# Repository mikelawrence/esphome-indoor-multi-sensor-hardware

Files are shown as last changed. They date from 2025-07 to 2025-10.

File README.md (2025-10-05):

# ESPHome Indoor Multi-Sensor Hardware

<p align="center">
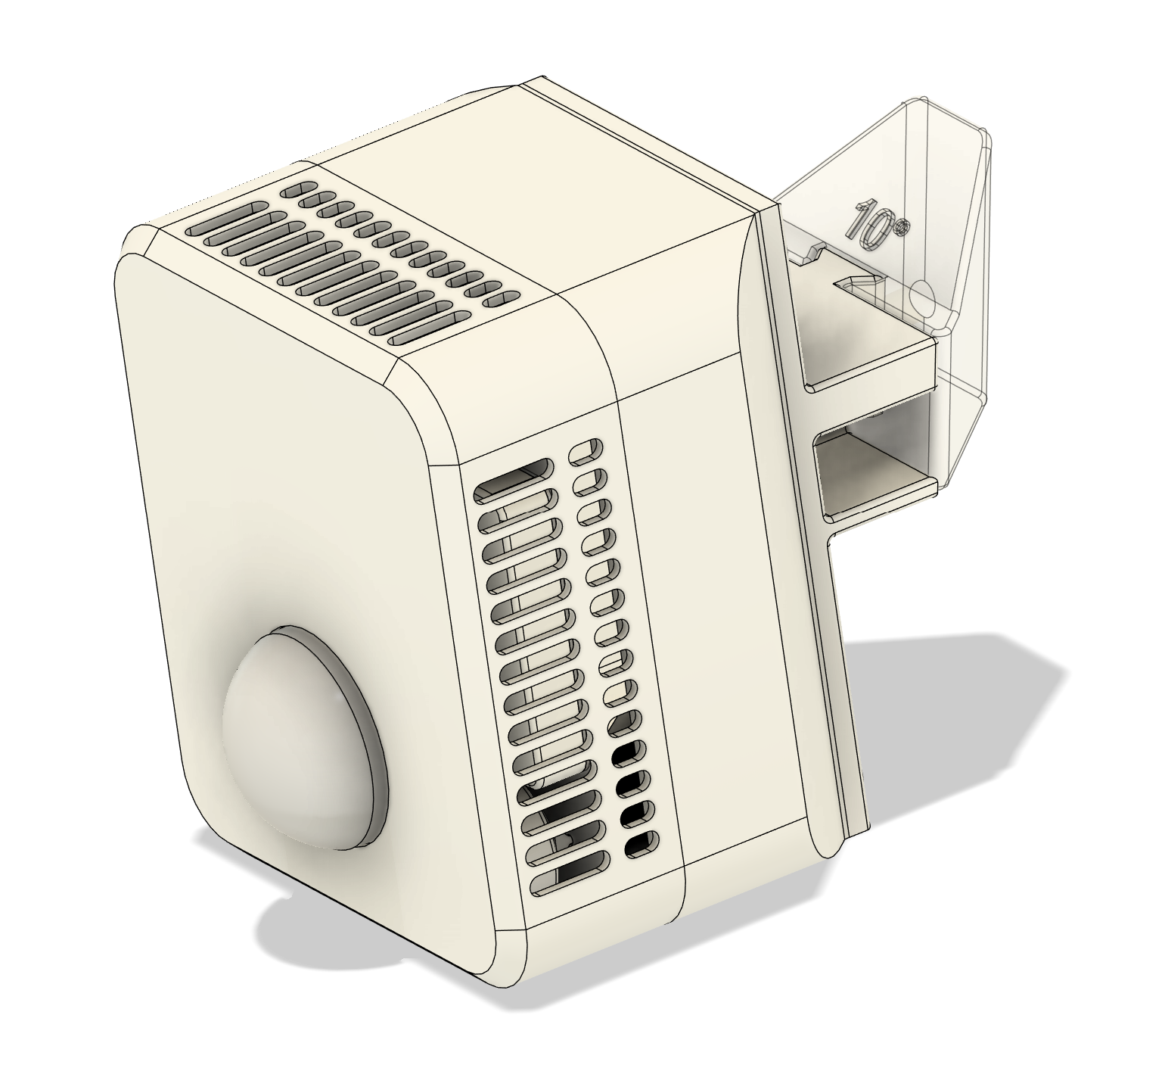
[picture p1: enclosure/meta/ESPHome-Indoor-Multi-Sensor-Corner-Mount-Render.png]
  
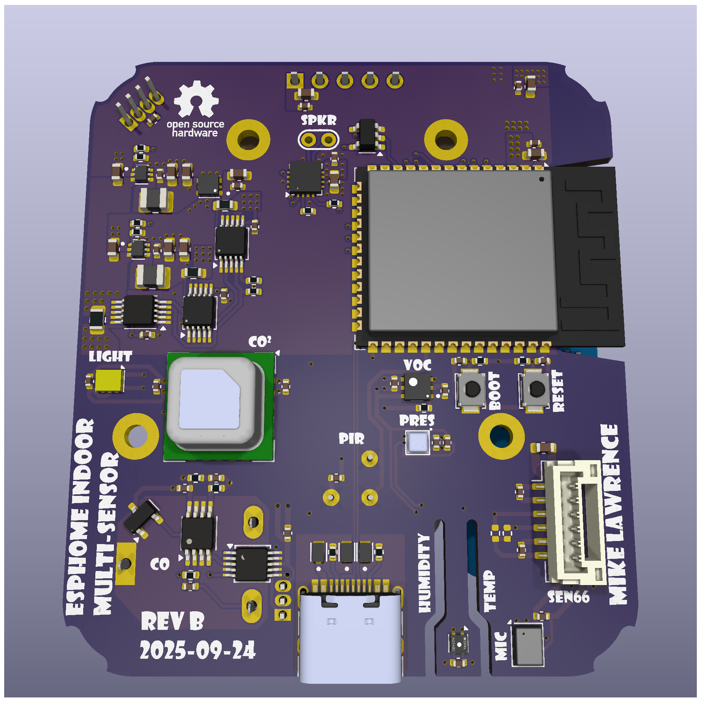
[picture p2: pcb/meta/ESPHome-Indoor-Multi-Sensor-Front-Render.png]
  
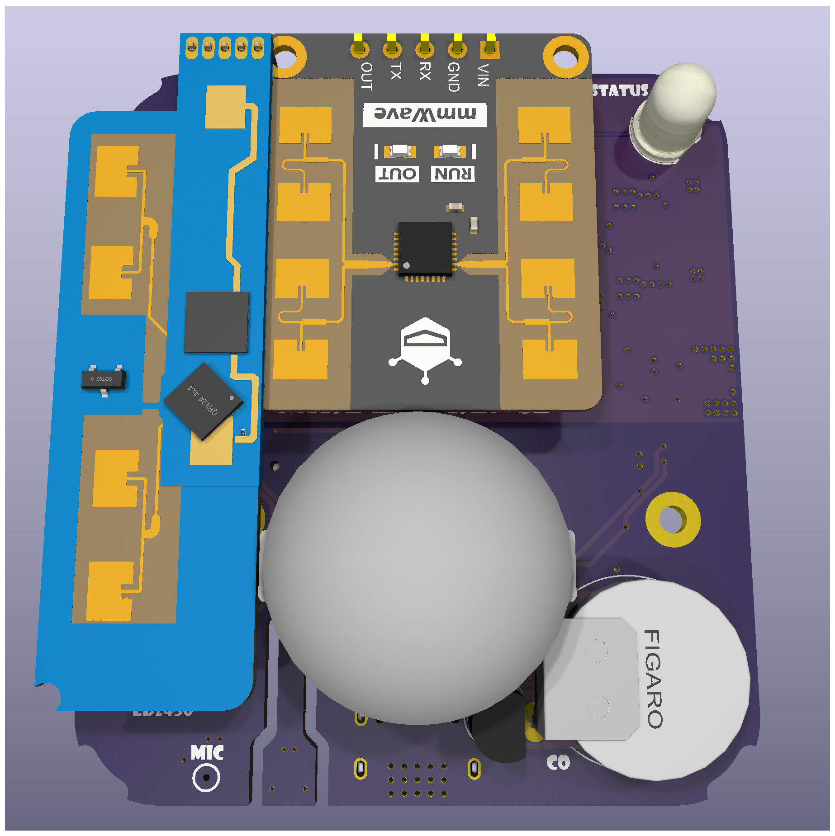
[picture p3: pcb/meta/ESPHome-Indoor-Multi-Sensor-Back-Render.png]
  
</p>

There are a lot of presence sensors using a combination of PIR and High Frequency Radar Human Presence Detectors to get a combination of quick response and low movement detection like when sleeping. Good examples of these types of sensor are the [Everything Presence One](https://shop.everythingsmart.io/products/everything-presence-one-kit) and [Roomsense IQ](https://www.roomsenselabs.com/). The later has a sensor module that you can add to support all sorts readings like Particular Matter (PM) Carbon Monoxide. But since I like to do everything myself. I started thinking about how I would approach this and more specifically what sensors did I want.

I settled on the following characteristics:

* ESP32-S3
* ESPHome software development
* USB-C Power
* Multiple options for Radar presence detection modules
  - Hi-Link LD2410B
  - Hi-Link LD2410S
  - Hi-Link LD2420
  - Hi-Link LD2450
  - DFRobot C4001 (SEN609 and SEN610)
* PIR (Panasonic)
* Sensirion SEN66 All-in-One (Package A)
  - Temperature
  - Humidity
  - Particulate Matter (PM) 
  - CO₂
  - Volatile Organic Compound (VOC)
  - Nitrogen Oxide (NOₓ)
* Or individual Sensors (Package B)
  - Sensirion SHT4X Temperature and Humidity
  - Sensirion SCD4X CO₂
  - Sensirion SGP4X VOC and NOₓ
* Bosch BMP581 Pressure
* Figaro TGS5141 Carbon Monoxide (CO)
* AMS TSL2591 Light
* Microphone for sound levels
* A Speaker for alerts
* INA228 Power and Energy Monitor

## Status
* **Rev -:** Has been fabricated and tested. I had JLCPCB fabricate the boards and I self assembled using a Home-Brew reflow oven by [Whizoo Controleo3](https://whizoo.com/). All circuits have been tested and found to be operational. 
* **Rev A:** There was an issue with signal integrity on the I²C bus when communicating with the SEN66. To fix the problem I added stronger pullups and a new and dedicated I²C bus to the SEN66. Thus Rev A was born. This revision was never fabricated. But all my Rev - boards have been modified to Rev A.
* **Rev B:** Added support for the LD2410S/LD2420 Radars, CO temperature sensor and INA238 power monitors for 3.3V and 3.3VA. Removed Radar power control. Board has been fabricated and testing has begun.

## Design Decisions
### ESP32 and ESPHome
ESPHome is closely aligned with Home Assistant. In fact they are the same company. Home Assistant uses ESPHome for some of their hardware like the [Home Assistant Voice Preview Edition](https://www.home-assistant.io/voice-pe/) or [Bluetooth Proxy](https://esphome.io/components/bluetooth_proxy.html). I chose a newer ESP32-S3 for this design which also has Bluetooth support.

This project uses ESP32-S3-WROOM-2-N32R16V which has an enormous 32MB of flash and 16MB of octal PSRAM. These specs are way out of the normal range for an ESP32, so why? First I wanted to be able to store sounds directly on the unit itself mainly so it can sound out alerts even if Home Assistant is not connected. The PSRAM came along with the big Flash but it also has benefits. Sound pressure analysis likes more PSRAM and so does Bluetooth Proxying.

### Sensors
#### Radar based Human Presence Sensors
Three of the Hi-Link sensors (LS2410B, LD2420 and LD2450) are supported by ESPHome directly but the DFRobot C4001 and LD2410S are not directly supported. This project uses the LD2410 component without change. For the LD2450 I have created a config that allows you to specify an installation angle, handle coordinate transforms and all zone detection. I created (with help from the Internet) a nice Home Assistant Lovelace configuration to visualize the installation angle and zone [here](https://mikelawrence.github.io/esphome-indoor-multi-sensor-config/home-assistant.html) for the LD2450 Radar and the LD2410 Radar's Gate configuration. For the DFRobot C4001 Radar I wrote an ESPHome External Component and created a [Pull Request](https://github.com/esphome/esphome/pull/9810) to add it to ESPHome. However the DFRobot team has since started their own [Pull Request](https://github.com/esphome/esphome/pull/10675). I will add support for their Pull Request when it comes out of draft and works. There is a [Pull Request](https://github.com/esphome/esphome/pull/8486) for the LD2410S. I will add support soon for the LD2410S and LD2420 Radars.

#### Sensor choices
The [SEN66](https://sensirion.com/products/catalog/SEN66) may be an expensive sensor package but it does it all, Temperature, Humidity, PM, CO₂, VOC and NOₓ. A tiny fan is primarily used for measuring PM but it also moves air by the temperature and humidity sensors making them fairly responsive. I call this Package A. If you choose not use the SEN66 you can populate the Package B individual sensors ([SHT4X](https://sensirion.com/media/documents/33FD6951/67EB9032/HT_DS_Datasheet_SHT4x_5.pdf), [SCD4X](https://sensirion.com/media/documents/48C4B7FB/67FE0194/CD_DS_SCD4x_Datasheet_D1.pdf) and [SGP4X](https://sensirion.com/media/documents/A056FE9C/61E970C2/Sensirion_Flyer_Gas_Sensors_Web.pdf)) to get Temperature, Humidity, CO₂, VOC and NOₓ. The only thing missing is PM.

#### Carbon Monoxide
For some reason CO sensors are not as common as CO₂ sensors. Most are expensive and have short life spans. The  Figaro TGS5141 is inexpensive and has a 10-year life span but it isn't a nice all-in-one with I²C interface. You have to add a transimpedance amplifier and then digitize the analog signal. I chose to add an ADS1115 16-bit ADC right next to the transimpedance amplifier instead of running analog signal across the board to the questionable ESP32 built in ADC. The ADS1115 also a has true differential Programmable Gain Amplifier on the input. This reduces the CO sensor circuit complexity. This sensor is not going to be very accurate but detection of CO in even low levels is probably a reason for concern. So even if not a safety sensor it can help.

I verified the CO circuit using CO Bump Gas. It doesn't calibrate, but it will prove that the sensor responds to the presence of CO. I used a small upside down container on my outside bench with the sensor I wanted to test inside. Squirting some bump gas inside with the thin straw showed that 4 out of 5 sensors responded to the gas. The 5'th that didn't respond had a solder bridge between two pins on the transimpedance amplifier. A quick removal of the solder bridge fixed the non-functioning sensor.

Rev B adds a DS18S20 temperature sensor to the design for CO calibration. The intent is to glue it to the CO sensor and use that for temperature calibration instead of using the ambient temp or the SHT4X sensor on the other side of the board.

> [!WARNING]
> This CO sensor is not rated for safety nor is it particularly accurate. Use at your own risk! I still have UL listed (American) CO detectors as my main line of defense.

#### Pressure and Light
The [BMP581](https://www.bosch-sensortec.com/media/boschsensortec/downloads/datasheets/bst-bmp581-ds004.pdf) pressure sensor is primarily used as a barometric pressure sensor but it is sensitive enough for micro-pressure changes like when a door is closed. Pressure can also be used to compensate the CO₂ sensor in either the SEN6X or the SCD4X. Light is another measurement that may or may not be helpful but I included it. Keep in mind that this measurement is inside an enclosure thus has some significant limitations when it comes to accuracy.

#### Speaker and Microphone
The SEN66 takes up a lot of space so a small speaker is necessary. I choose a flat speaker from [Same Sky](https://www.sameskydevices.com/product/audio/speakers/miniature-(10-mm~40-mm)/cms-251437-24sp-x8) and started playing. My first attempts were pretty, flat, meaning these small speakers don't move a lot of air and in free space they have almost no volume. After doing some research it became clear, the speaker needs a enclosure. I was able to come up with a small 3D printed enclosure attached to the PCB itself. Man what a difference. This 2W speaker kicks some serious butt.

I threw in the microphone to measure sound levels. The intent is listen for noise as additional presence detection.

#### Power and Energy Monitor
The [INA228](https://www.ti.com/lit/ds/symlink/ina228.pdf) power and energy monitor can give instantaneous readings of voltage, current and power but it also measures energy over time (WHr).

### USB-C Power
The board does not use USB-C Power Delivery but I am expecting 5V @ 3A which is readily available for most USB-C Power Bricks. The PCB has the appropriate resistors on the CC pins which will request 5V @ 3A from a USB-C Power Brick. The board does not need anywhere close to 3A but peaks near 0.75A are possible so be careful using a USB 2.0 Power Brick with a 0.5A default current. Actual testing shows a 1W average for the Package A version and slightly less than 0.9W average for the Package B option as measured by the INA228. Quick calculations show about 8.1kWh/yr for Package A and 7.3kWh/yr for Package B. In Texas that is less than $1 per year. These number are for Rev -.

## Enclosure
<p align="center">
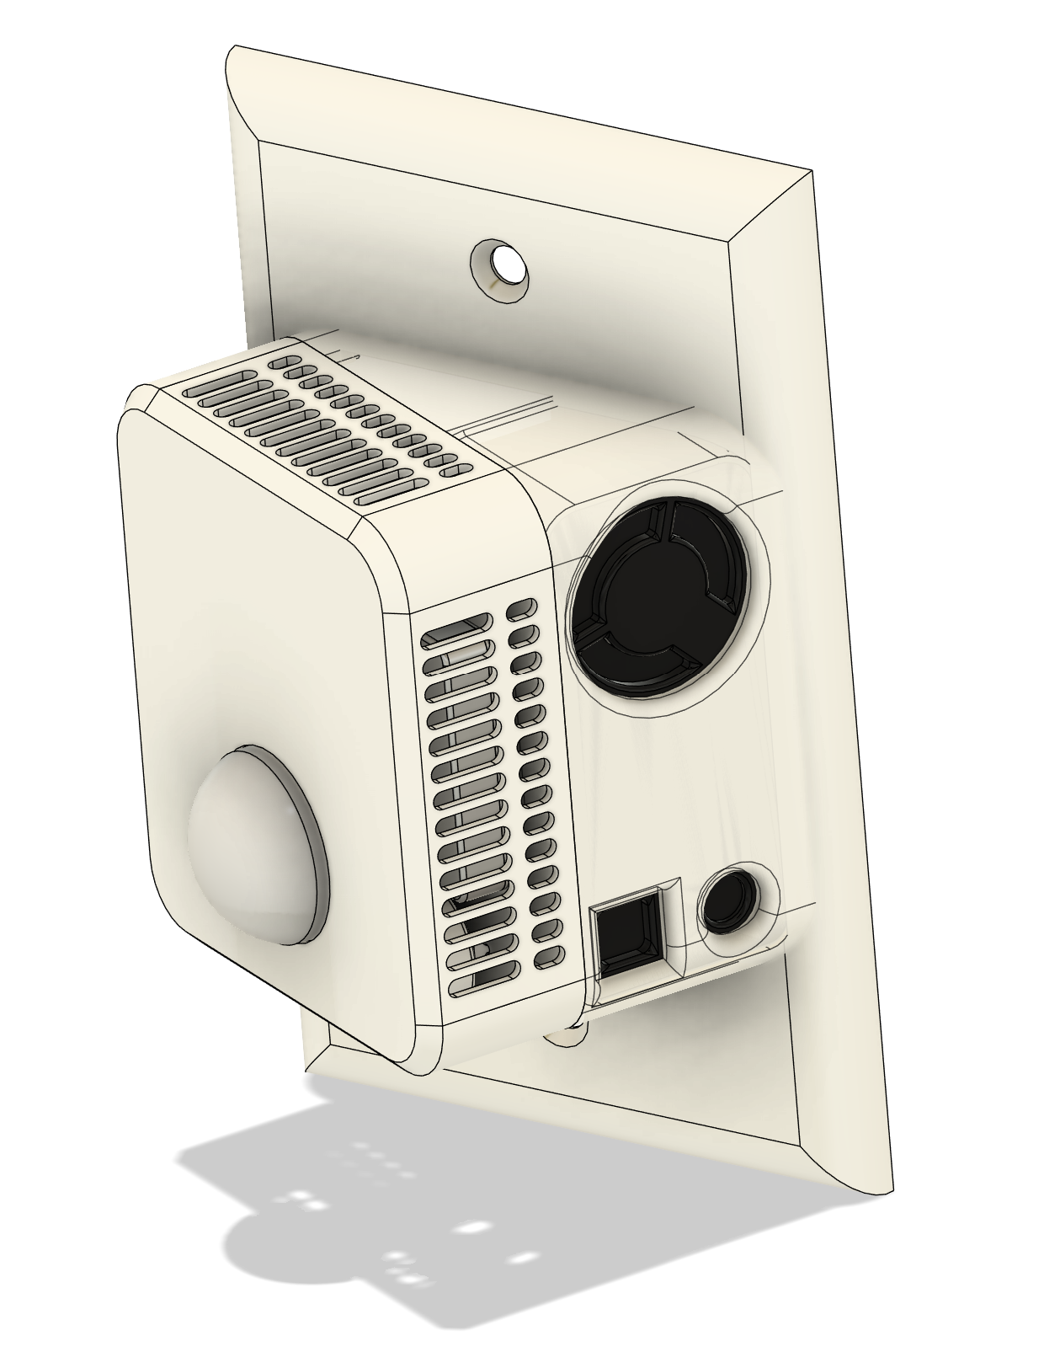
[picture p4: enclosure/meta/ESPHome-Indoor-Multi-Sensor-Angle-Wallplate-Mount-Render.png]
  
</p>

More information is in the enclosure [README](enclosure/README.md) file.

## Configuration
Click [here](https://mikelawrence.github.io/esphome-indoor-multi-sensor-config/) to go to the installation and configuration repository.

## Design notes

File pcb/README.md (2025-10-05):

# ESPHome Indoor Multi-Sensor PCB
<p align="center">
  
  
</p>

The PCB is designed in [KiCad](https://www.kicad.org/). Fabrication and is tuned toward [JCLPCB](https://jlcpcb.com/). I chose not to use JLCPCB for assembly because they had a hard time with some the parts I included in this design. When I had the boards fabricated I also had them panelize two PCBs and produce a stencil for both for the panelized boards.

* **Rev -**: Is currently being fabricated. 

## Schematic
<p align="center">
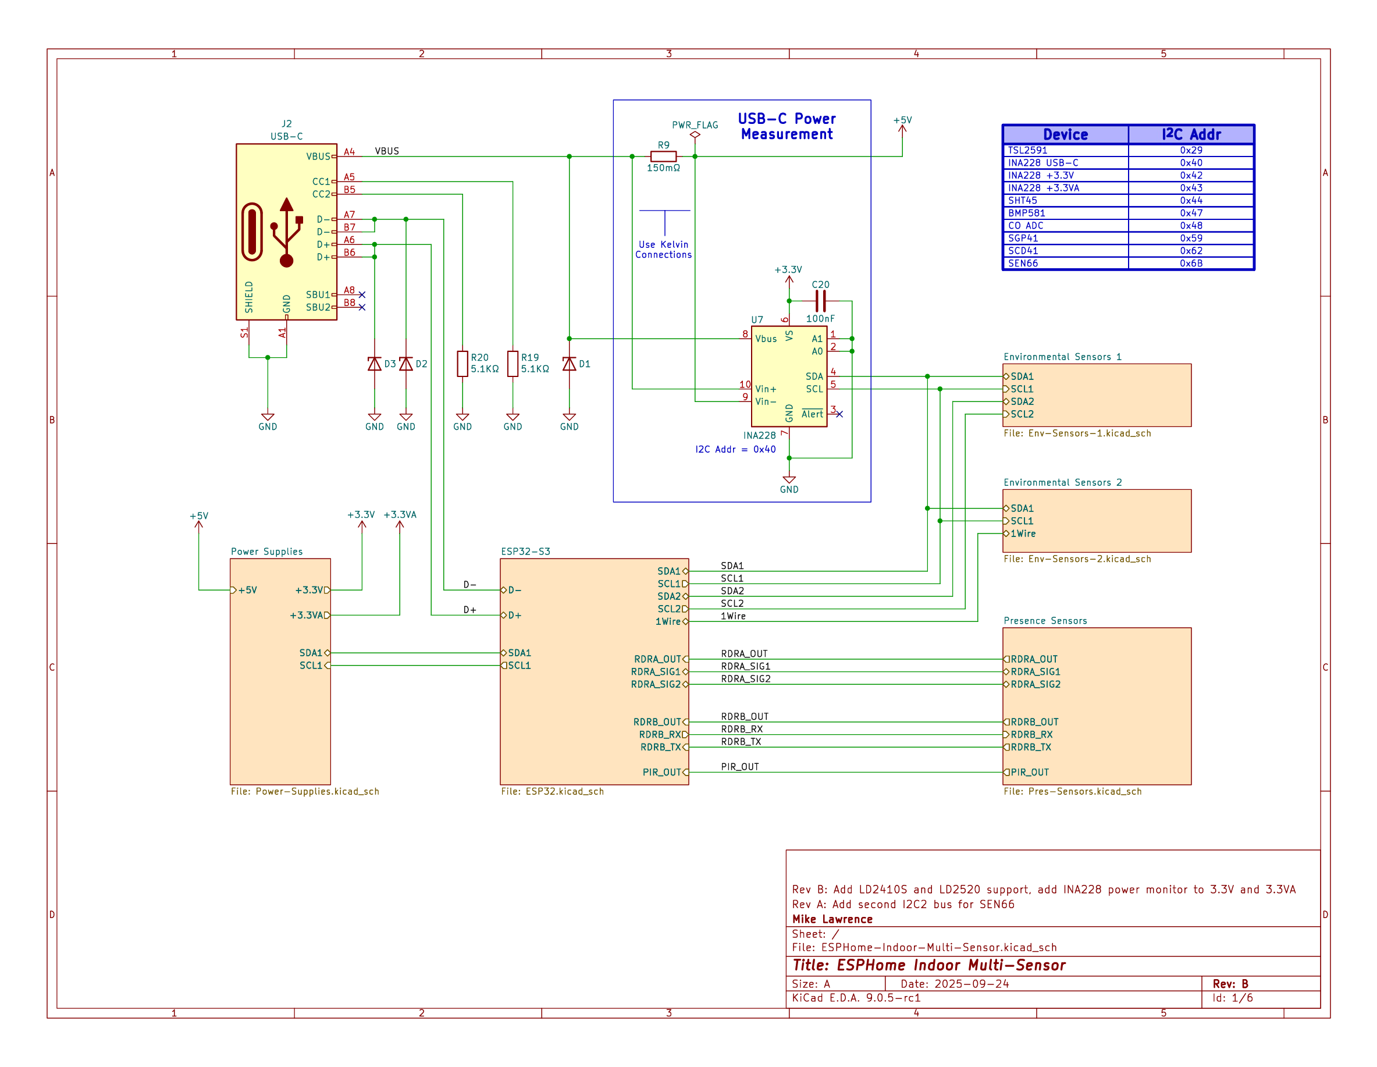
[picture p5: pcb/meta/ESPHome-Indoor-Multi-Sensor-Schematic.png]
     <br />
    Schematic
</p>

### Do Not Populate (DNP) Notes
When you use the SEN66 from Sensirion you don't need to install discrete sensor components ```U11```, ```U12```, ```U16```, ```C29```, ```C29```, ```C30```, ```C31``` or ```C43```.

## Bill of Materials
<p align="center">
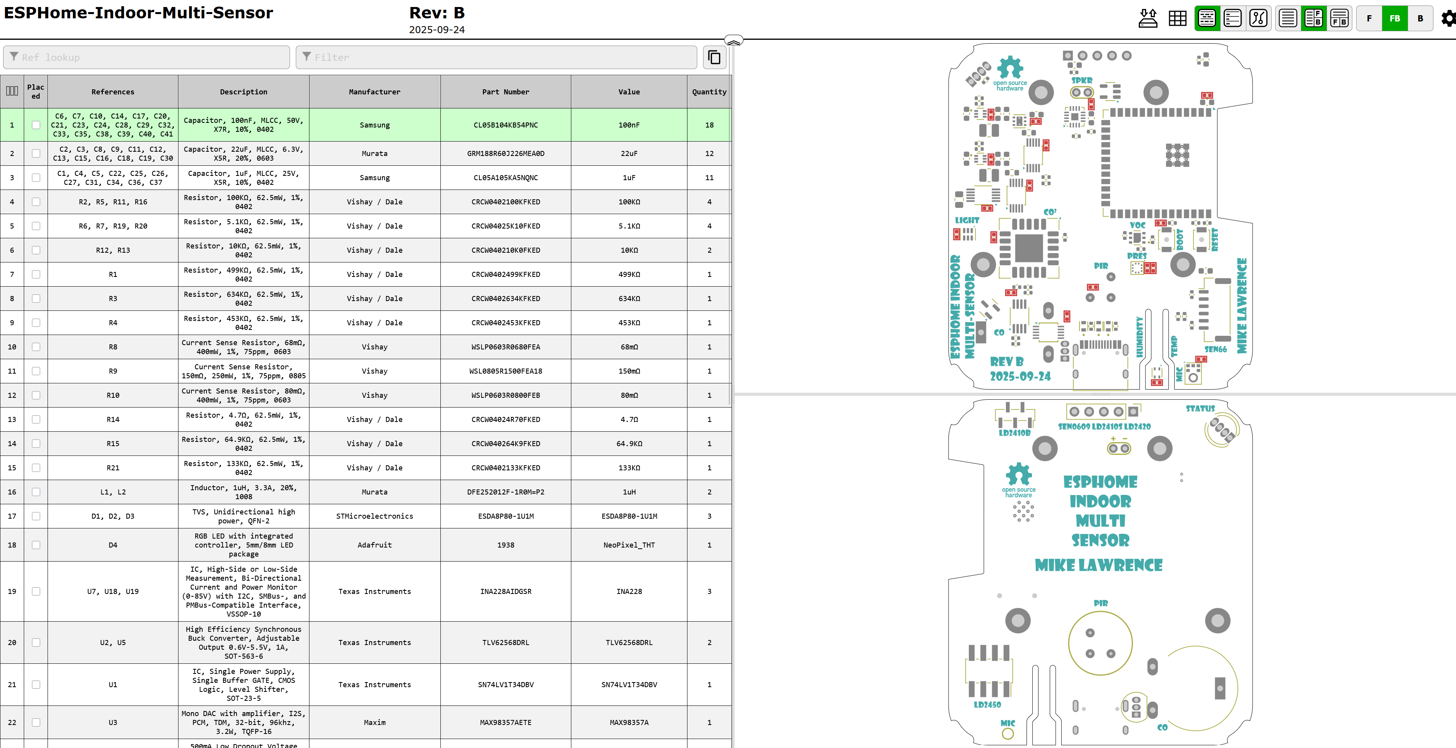
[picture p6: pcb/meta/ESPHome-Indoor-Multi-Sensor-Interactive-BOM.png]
     <br />
    Interactive BOM
</p>

## PCB Info
* 4 layer to support an additional ground plane and signal layer to reduce plane interruptions on the outer layers.
* There has been an attempt thermally isolate the SHT4X Temperature and Humidity Sensor but there are no guarantees.
* Dimensions are 52.5mm X 59.7mm.
* Requires oven reflow or hot air to assemble most components.

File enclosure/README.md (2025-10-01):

# ESPHome Indoor Multi-Sensor Enclosure

These models are designed in Fusion 360

## Corner Mount
<p align="center">
    
</p>

This 3D printable enclosure is designed to go into a corner. There is a `Wall_Angle` parameter that point the sensor downward. It produces a two-piece mount. Thew first part is screwed to the to back of the sensor and it also holds the SEN66 sensor in place. The second part is the corner mount (screwed the corner of your room with an M3 wood screw). The sensor just slides on the corner mount.

Included in the design is a speaker enclosure that mounts to the PCB with M2x6mm button head screws. The improves sound level. Both the speaker enclosure and back mount have TPU gaskets.

The front body, with or without a hole for the PIR sensor, snaps into the back body and holds the PCB in place. A small cable connects the SEN66 to the PCB must be in place before snaps the bodies together.

The Corner Mount Fusion design is available [here](https://github.com/mikelawrence/ESPHome-Indoor-Multi-Sensor/raw/refs/heads/main/enclosure/ESPHome-Multi-Sensor-Corner-Mount-Enclosure.f3z).

[Here](https://github.com/mikelawrence/ESPHome-Indoor-Multi-Sensor/raw/refs/heads/main/enclosure/3d-printing/Corner-Mount/ESPHome-Indoor-Multi-Sensor-Corner-Mount-Bambu-Stu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) is a BambuLab file with all the parts ready for you to print.

Independent `STEP` files are also available in the `3d-printing folder`.

## Angle Wallplate Mount
<p align="center">
    
</p>

This 3D printable enclosure is designed to mount on a US Wallplate. There are four versions: Left Facing with SEN66, Right Facing with SEN66, Left Facing, and Right Facing. This is similar to the Corner mount without the angle adjustment. 

The Angle Wallplate FUsion design file is [here](https://github.com/mikelawrence/esphome-indoor-multi-sensor-hardware/raw/refs/heads/main/enclosure/ESPHome-Multi-Sensor-Angle-Wallplate-Enclosure.f3z).

[Here](https://github.com/mikelawrence/esphome-indoor-multi-sensor-hardware/raw/refs/heads/main/enclosure/3d-printing/Angle-Wallplate/ESPHome-Indoor-Multi-Sensor-Angle-Wall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) is a BambuLab file with all the parts ready for you to print.

Independent `STEP` files are also available in the `3d-printing folder`.

# Additional Models

## DFRobot C4001 SEN0609 Module
I couldn't find a step model of this Radar so I made one. Here is the [Fusion model](https://github.com/mikelawrence/ESPHome-Indoor-Multi-Sensor/raw/refs/heads/main/enclosure/DFRobot-C4001-SEN0609.f3z) and a [STEP model](https://github.com/mikelawrence/ESPHome-Indoor-Multi-Sensor/raw/refs/heads/main/enclosure/DFRobot-C4001-SEN0609.step).

## Hi-Link Electronics LD-2450 Module
The LD2450 Module I found were missing the front antennas and back header so I added these to the model from Hi-Link Electronics. Here is the [Fusion model](https://github.com/mikelawrence/ESPHome-Indoor-Multi-Sensor/raw/refs/heads/main/enclosure/HLK-LD2450-3D.f3z) and the [STEP model](https://github.com/mikelawrence/ESPHome-Indoor-Multi-Sensor/raw/refs/heads/main/enclosure/HLK-LD2450-3D.step).

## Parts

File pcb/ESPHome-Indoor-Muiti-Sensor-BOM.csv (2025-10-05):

Qty | Reference | Value | Description | DNP | Manufacturer | Part Number
11 | C1,C4,C5,C22,C25,C26,C27,C31,C34,C36,C37 | 1uF | Capacitor, 1uF, MLCC, 25V, X5R, 10%, 0402 |  | Samsung | CL05A105KA5NQNC
12 | C2,C3,C8,C9,C11,C12,C13,C15,C16,C18,C19,C30 | 22uF | Capacitor, 22uF, MLCC, 6.3V, X5R, 20%, 0603 |  | Murata | GRM188R60J226MEA0D
18 | C6,C7,C10,C14,C17,C20,C21,C23,C24,C28,C29,C32,C33,C35,C38,C39,C40,C41 | 100nF | Capacitor, 100nF, MLCC, 50V, X7R, 10%, 0402 |  | Samsung | CL05B104KB54PNC
1 | D4 | NeoPixel_THT | RGB LED with integrated controller, 5mm/8mm LED package |  | Adafruit | 1938
3 | D1,D2,D3 | ESDA8P80-1U1M | TVS, Unidirectional high power, QFN-2 |  | STMicroelectronics | ESDA8P80-1U1M
1 | J1 | SEN66 | 6-Position, 1.25 mm pitch, Wire-to-Board connector |  | JST | BM06B-GHS-TBT
1 | J2 | USB-C | Connector, USB 2.0, 16P, Type-C, Receptacle |  | Phoenix Contact | 1332645
1 | J3 | SEN0609 | Generic connector, 2.54mm spacing, single row, 01x05 (TLW-105-06-T-S) |  | Samtec | CES-105-01-T-S
1 | J4 | LD2410 | Generic connector, 1.27mm spacing, single row, 01x05 |  | Samtec | RSM-105-02-S-S
1 | J5 | SPKR | Solder Holes for up to 24 ga wire |  | Same Sky | CMS-251437-24SP-X8
1 | J6 | LD2450 | Socket, 8 position, 2mm spacing, dual row, 02x04, SMT |  | Molex | 79109-1003
2 | L1,L2 | 1uH | Inductor, 1uH, 3.3A, 20%, 1008 |  | Murata | DFE252012F-1R0M=P2
1 | MK1 | ICS-43434 | TDK InvenSense MEMS Microphone, 24-bit I2S, 65 dBA SNR, LGA-6 |  | TDK InvenSense | ICS-43434
1 | Q1 | MMBFJ201 | 20mA min, 35V, 30mOhm max, 3-10V Vgs(off), N-Channel JFET, SOT-23 |  | Onsemi | MMBFJ201
1 | R1 | 499KΩ | Resistor, 499KΩ, 62.5mW, 1%, 0402 |  | Vishay / Dale | CRCW0402499KFKED
1 | R3 | 634KΩ | Resistor, 634KΩ, 62.5mW, 1%, 0402 |  | Vishay / Dale | CRCW0402634KFKED
1 | R4 | 453KΩ | Resistor, 453KΩ, 62.5mW, 1%, 0402 |  | Vishay / Dale | CRCW0402453KFKED
1 | R8 | 68mΩ | Current Sense Resistor, 68mΩ, 400mW, 1%, 75ppm, 0603 |  | Vishay | WSLP0603R0680FEA
1 | R9 | 150mΩ | Current Sense Resistor, 150mΩ, 250mW, 1%, 75ppm, 0805 |  | Vishay | WSL0805R1500FEA18
1 | R10 | 80mΩ | Current Sense Resistor, 80mΩ, 400mW, 1%, 75ppm, 0603 |  | Vishay | WSLP0603R0800FEB
1 | R14 | 4.7Ω | Resistor, 4.7Ω, 62.5mW, 1%, 0402 |  | Vishay / Dale | CRCW04024R70FKED
1 | R15 | 64.9KΩ | Resistor, 64.9KΩ, 62.5mW, 1%, 0402 |  | Vishay / Dale | CRCW040264K9FKED
1 | R21 | 133KΩ | Resistor, 133KΩ, 62.5mW, 1%, 0402 |  | Vishay / Dale | CRCW0402133KFKED
2 | R12,R13 | 10KΩ | Resistor, 10KΩ, 62.5mW, 1%, 0402 |  | Vishay / Dale | CRCW040210K0FKED
4 | R2,R5,R11,R16 | 100KΩ | Resistor, 100KΩ, 62.5mW, 1%, 0402 |  | Vishay / Dale | CRCW0402100KFKED
6 | R6,R7,R17,R18,R19,R20 | 5.1KΩ | Resistor, 5.1KΩ, 62.5mW, 1%, 0402 | DNP | Vishay / Dale | CRCW04025K10FKED
1 | SW1 | BOOT | Switch, SMD |  | Omron | B3U-1000P
1 | SW2 | RESET | Switch, SMD |  | Omron | B3U-1000P
1 | U1 | SN74LV1T34DBV | IC, Single Power Supply, Single Buffer GATE, CMOS Logic, Level Shifter, SOT-23-5 |  | Texas Instruments | SN74LV1T34DBV
1 | U3 | MAX98357A | Mono DAC with amplifier, I2S, PCM, TDM, 32-bit, 96khz, 3.2W, TQFP-16 |  | Maxim | MAX98357AETE
1 | U4 | TLV75533PDRV | 500mA Low Dropout Voltage Regulator, Fixed Output 3.3V, WSON6 |  | Texas Instruments | TLV75533PDRV
1 | U6 | ESP32-S3-WROOM-2-N32R16V | RF Module, ESP32-S3 SoC, Wi-Fi 802.11b/g/n, Bluetooth, BLE, 32-bit, 3.3V, onboard antenna, SMD |  | Espressif | ESP32-S3-WROOM-2-N32R16V
1 | U7 | INA228 | IC, 85-V, 20-Bit, Ultra-Precise Power-Energy-Charge Monitor With I2C Interface, VSSOP-10 |  | Texas Instruments | INA228AIDGSR
1 | U8 | TSL2591 | Light to digital converter, 2.7 to 3.6V Vdd, DFN-6 |  | AMS | TSL2591
1 | U9 | SGP41 | Indoor Air Quality Sensor, MOx based, DFN-6 |  | Sensirion | SGP41-D-R4
1 | U10 | SCD41 | Photoacoustic CO2 sensor, I2C, 2.4-5.5 V, High accuracy 400 - 5000 ppm |  | Sensirion | SCD41-D-R2
1 | U11 | BMP581 | Barometric Pressure Sensor, 24-bit, Low-power and Low-noise, SMD |  | Bosch Sensortec | BMP581
1 | U12 | MCP6042 | Dual Operational Amplifiers, Rail-to-Rail Input/Output, MSOP-8 |  | Microchip | MCP6042T-I/MS
1 | U13 | ADS1115 | Ultra-Small, Low-Power, I2C-Compatible, 860-SPS, 16-Bit ADCs With Internal Reference, Oscillator, and Programmable Comparator, VSSOP-10 |  | Texas Instruments | ADS1115IDGS
1 | U14 | SHT45 | Digital Humidity and Temperature Sensor, ±1%RH, ±0.1°C, I2C, 1.08-3.6V, 16bit, DFN-4 |  | Sensirion | SHT45-AD1B-R2
1 | U15 | EKMC1603111 | Passive Infrared (PIR) Motion Sensor, THT |  | Panasonic | EKMC1603111
1 | U16 | TGS5141 | Carbon Monoxide Sensor, Long life, THT |  | Figaro | TGS5141-P00
1 | U17 | DS18S20 | High-Precision 1-Wire Digital Thermometer TO-92 |  | Maxim | DS18S20+
2 | U18,U19 | INA238 | IC, 85V, 16-Bit, High-Precision Power Monitor With I2C Interface, VSSOP-10 |  | Texas Instruments | INA238AIDGSR
2 | U2,U5 | TLV62568DRL | High Efficiency Synchronous Buck Converter, Adjustable Output 0.6V-5.5V, 1A, SOT-563-6 |  | Texas Instruments | TLV62568DRL

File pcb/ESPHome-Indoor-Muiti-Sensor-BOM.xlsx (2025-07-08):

Qty | Reference | Value | Description | DNP | Manufacturer | Part Number
13 | C1,C4,C5,C6,C8,C26,C29,C30,C31,C35,C38,C40,C41 | 1uF | Capacitor, 1uF, MLCC, 25V, X5R, 10%, 0402 |  | Samsung | CL05A105KA5NQNC
16 | C10,C11,C14,C18,C21,C24,C25,C27,C28,C32,C33,C36,C37,C39,C42,C43 | 100nF | Capacitor, 100nF, MLCC, 50V, X7R, 10%, 0402 |  | Samsung | CL05B104KB54PNC
12 | C2,C3,C12,C13,C15,C16,C17,C19,C20,C22,C23,C34 | 22uF | Capacitor, 22uF, MLCC, 6.3V, X5R, 20%, 0603 |  | Murata | GRM188R60J226MEA0D
2 | C7,C9 | 1nF | Capacitor, 1nF, MLCC, 50V, X7R, 10%, 0402 |  | KYOCERA AVX | 04023C102KAT2A
1 | D4 | NeoPixel_THT | RGB LED with integrated controller, 5mm/8mm LED package |  | Adafruit | 1938
3 | D1,D2,D3 | ESDA8P80-1U1M | TVS, Unidirectional high power, QFN-2 |  | STMicroelectronics | ESDA8P80-1U1M
1 | J1 | SEN66 | 6-Position, 1.25 mm pitch, Wire-to-Board connector |  | JST | BM06B-GHS-TBT
1 | J2 | USB-C | Connector, USB 2.0, 16P, Type-C, Receptacle |  | Phoenix Contact | 1332645
1 | J3 | SEN0609 | Generic connector, 2.54mm spacing, single row, 01x05 (TLW-105-06-T-S) |  | Samtec | CES-105-01-T-S
1 | J4 | LD2410 | Generic connector, 1.27mm spacing, single row, 01x05 |  | Samtec | RSM-105-02-S-S
1 | J5 | SPKR | Solder Holes for up to 24 ga wire |  | Same Sky | CMS-251437-24SP-X8
1 | J6 | LD2450 | Socket, 8 position, 2mm spacing, dual row, 02x04, SMT |  | Molex | 79109-1003
1 | JP3 | Gain | Header, 10 position, 2mm spacing, dual row, 02x05, SMT |  | Samtec | TMM-105-01-L-D-SM-P-TR
2 | L1,L2 | 1uH | Inductor, 1uH, 3.3A, 20%, 1008 |  | Murata | DFE252012F-1R0M=P2
1 | MK1 | ICS-43434 | TDK InvenSense MEMS Microphone, 24-bit I2S, 65 dBA SNR, LGA-6 |  | TDK InvenSense | ICS-43434
1 | Q1 | MMBFJ201 | 20mA min, 35V, 30mOhm max, 3-10V Vgs(off), N-Channel JFET, SOT-23 |  | Onsemi | MMBFJ201
1 | R3 | 499KÎ© | Resistor, 499KÎ©, 62.5mW, 1%, 0402 |  | Vishay / Dale | CRCW0402499KFKED
1 | R5 | 634KÎ© | Resistor, 634KÎ©, 62.5mW, 1%, 0402 |  | Vishay / Dale | CRCW0402634KFKED
1 | R6 | 453KÎ© | Resistor, 453KÎ©, 62.5mW, 1%, 0402 |  | Vishay / Dale | CRCW0402453KFKED
1 | R11 | 150mÎ© | Current Sense Resistor, 150mÎ©, 500mW, 1%, 1210 |  | Panasonic | ERJ-14BSFR15U
1 | R16 | 4.7Î© | Resistor, 4.7Î©, 62.5mW, 1%, 0402 |  | Vishay / Dale | CRCW04024R70FKED
1 | R17 | 64.9KÎ© | Resistor, 64.9KÎ©, 62.5mW, 1%, 0402 |  | Vishay / Dale | CRCW040264K9FKED
1 | R21 | 133KÎ© | Resistor, 133KÎ©, 62.5mW, 1%, 0402 |  | Vishay / Dale | CRCW0402133KFKED
6 | R1,R2,R4,R7,R13,R18 | 100KÎ© | Resistor, 100KÎ©, 62.5mW, 1%, 0402 |  | Vishay / Dale | CRCW0402100KFKED
2 | R10,R12 | 10Î© | Resistor, 10Î©, 62.5mW, 1%, 0402 |  | Vishay / Dale | CRCW040210R0FKEE
2 | R14,R15 | 10KÎ© | Resistor, 10KÎ©, 62.5mW, 1%, 0402 |  | Vishay / Dale | CRCW040210K0FKED
2 | R19,R20 | 5.1KÎ© | Resistor, 5.1KÎ©, 62.5mW, 1%, 0402 |  | Vishay / Dale | CRCW04025K10FKED
2 | R8,R9 | DNP | Resistor, Do Not Populate, 0402 | DNP
1 | SW1 | BOOT | Switch, SMD |  | Omron | B3U-1000P
1 | SW2 | RESET | Switch, SMD |  | Omron | B3U-1000P
1 | U3 | SN74LV1T34DBV | IC, Single Power Supply, Single Buffer GATE, CMOS Logic, Level Shifter, SOT-23-5 |  | Texas Instruments | SN74LV1T34DBV
1 | U5 | MAX98357A | Mono DAC with amplifier, I2S, PCM, TDM, 32-bit, 96khz, 3.2W, TQFP-16 |  | Maxim | MAX98357AETE
1 | U6 | TLV75533PDRV | 500mA Low Dropout Voltage Regulator, Fixed Output 3.3V, WSON6 |  | Texas Instruments | TLV75533PDRV
1 | U8 | ESP32-S3-WROOM-2-N32R16V | RF Module, ESP32-S3 SoC, Wi-Fi 802.11b/g/n, Bluetooth, BLE, 32-bit, 3.3V, onboard antenna, SMD |  | Espressif | ESP32-S3-WROOM-2-N32R16V
1 | U9 | INA228 | IC, High-Side or Low-Side Measurement, Bi-Directional Current and Power Monitor (0-85V) with I2C, SMBus-, and PMBus-Compatible Interface, VSSOP-10 |  | Texas Instruments | INA228AIDGSR
1 | U10 | TSL2591 | Light to digital converter, 2.7 to 3.6V Vdd, DFN-6 |  | AMS | TSL2591
1 | U11 | SGP41 | Indoor Air Quality Sensor, MOx based, DFN-6 |  | Sensirion | SGP41-D-R4
1 | U12 | SCD41 | Photoacoustic CO2 sensor, I2C, 2.4-5.5 V, High accuracy 400 - 5000 ppm |  | Sensirion | SCD41-D-R2
1 | U13 | BMP581 | Barometric Pressure Sensor, 24-bit, Low-power and Low-noise, SMD |  | Bosch Sensortec | BMP581
1 | U14 | MCP6042 | Dual Operational Amplifiers, Rail-to-Rail Input/Output, MSOP-8 |  | Microchip | MCP6042T-I/MS
1 | U15 | ADS1115 | Ultra-Small, Low-Power, I2C-Compatible, 860-SPS, 16-Bit ADCs With Internal Reference, Oscillator, and Programmable Comparator, VSSOP-10 |  | Texas Instruments | ADS1115IDGS
1 | U16 | SHT45 | Digital Humidity and Temperature Sensor, Â±1%RH, Â±0.1Â°C, I2C, 1.08-3.6V, 16bit, DFN-4 |  | Sensirion | SHT45-AD1B-R2
1 | U17 | EKMC1603111 | Passive Infrared (PIR) Motion Sensor, THT |  | Panasonic | EKMC1603111
1 | U18 | TGS5141 | Carbon Monoxide Sensor, Long life, THT |  | Figaro | TGS5141-P00
2 | U1,U2 | TPS22917DBV | 1V to 5.5V, 2A, 80mÎ© Ultra-Low Leakage Load Switch, SOT23-6 |  | Texas Instruments | TPS22917DBV
2 | U4,U7 | TLV62568DRL | High Efficiency Synchronous Buck Converter, Adjustable Output 0.6V-5.5V, 1A, SOT-563-6 |  | Texas Instruments | TLV62568DRL

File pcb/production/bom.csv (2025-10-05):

Designator | Footprint | Quantity | Value | LCSC Part #
C1, C22, C25, C26, C27, C31, C34, C36, C37, C4, C5 | 0402 | 11 | 1uF | C52923
C10, C14, C17, C20, C21, C23, C24, C28, C29, C32, C33, C35, C38, C39, C6, C7 | 0402 | 16 | 100nF | C307331
C11, C12, C13, C15, C16, C18, C19, C2, C3, C30, C8, C9 | 0603 | 12 | 22uF | C77042
C40, C41 | 0402 | 2 | 100nF
D1, D2, D3 | TVS_ESDA25P35-1U1M | 3 | ESDA8P80-1U1M
D4 | LED_D5.0mm-4_RGB | 1 | NeoPixel_THT
J1 | JST_GH_BM06B-GHS-TBT_1x06-1MP_P1.25mm_Vertical | 1 | SEN66 | C189892
J2 | USB_C_Receptacle_HRO_TYPE-C-31-M-12 | 1 | USB-C
J3 | PinHeader_1x05_P2.54mm_Vertical | 1 | SEN0609
J4 | PinSocket_1x05_P1.27mm_Vertical_SMD_Pin1Right | 1 | LD2410
J5 | PinHeader_1x02_P2.00mm_Vertical | 1 | SPKR
J6 | PinSocket_2x04_P2.00mm_Vertical_SMD | 1 | LD2450
L1, L2 | 1008 | 2 | 1uH | C435392
MK1 | InvenSense_ICS-43434-6_3.5x2.65mm | 1 | ICS-43434
Q1 | SOT-23 | 1 | MMBFJ201 | C891687
R1 | 0402 | 1 | 499KΩ
R10 | 0603 | 1 | 80mΩ
R11, R16, R2, R5 | 0402 | 4 | 100KΩ
R12, R13 | 0402 | 2 | 10KΩ
R14 | 0402 | 1 | 4.7Ω
R15 | 0402 | 1 | 64.9KΩ
R19, R20, R6, R7 | 0402 | 4 | 5.1KΩ
R21 | 0402 | 1 | 133KΩ
R3 | 0402 | 1 | 634KΩ
R4 | 0402 | 1 | 453KΩ
R8 | 0603 | 1 | 68mΩ
R9 | 0805 | 1 | 150mΩ
SW1 | SW_SPST_B3U-1000P-B | 1 | BOOT | C231329
SW2 | SW_SPST_B3U-1000P-B | 1 | RESET | C231329
U1 | SOT-23-5 | 1 | SN74LV1T34DBV | C100024
U10 | Sensirion_SCD4x-1EP_10.1x10.1mm_P1.25mm_EP4.8x4.8mm | 1 | SCD41
U11 | BMP581 | 1 | BMP581
U12 | MSOP-8_3x3mm_P0.65mm | 1 | MCP6042 | C627438
U13 | TSSOP-10_3x3mm_P0.5mm | 1 | ADS1115 | C37593
U14 | Sensirion_DFN-4_1.5x1.5mm_P0.8mm_SHT4x_NoCentralPad | 1 | SHT45
U15 | EKMC163111 | 1 | EKMC1603111
U16 | TGS-5141 | 1 | TGS5141
U17 | TO-92_Inline | 1 | DS18S20
U18, U19 | VSSOP-10_3x3mm_P0.5mm | 2 | INA238
U2, U5 | SOT50P160X60-6N | 2 | TLV62568DRL | C398372
U3 | TQFN-16-1EP_3x3mm_P0.5mm_EP1.23x1.23mm | 1 | MAX98357A
U4 | VREG_TLV75533PDRVR | 1 | TLV75533PDRV
U6 | ESP32-S3-WROOM-2 | 1 | ESP32-S3-WROOM-2-N32R16V
U7 | VSSOP-10_3x3mm_P0.5mm | 1 | INA228 | C2887910
U8 | AMS_TSL25911FN | 1 | TSL2591
U9 | XCDR_SGP40-D-R4 | 1 | SGP41

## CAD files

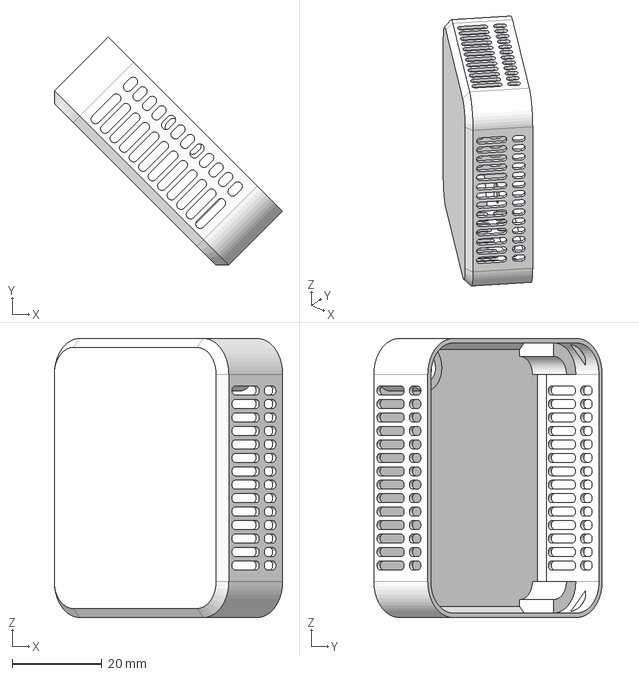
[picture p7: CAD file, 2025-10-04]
enclosure/3d-printing/Angle-Wallplate/ESPHome-Indoor-Multi-Sensor-Angle-Wallplate-Front-Body-No-PIR.step
50.9 x 50.9 x 62.2 mm

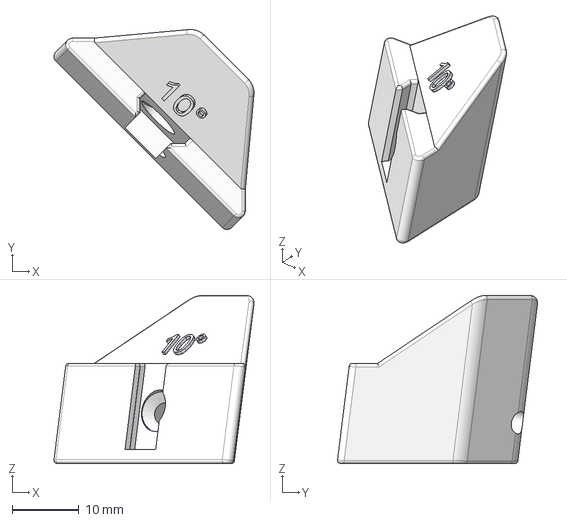
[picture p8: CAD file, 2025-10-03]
enclosure/3d-printing/Corner-Mount/ESPHome-Indoor-Multi-Sensor-Corner-Corner-Mount-10°.step
29.9 x 29.9 x 25.1 mm

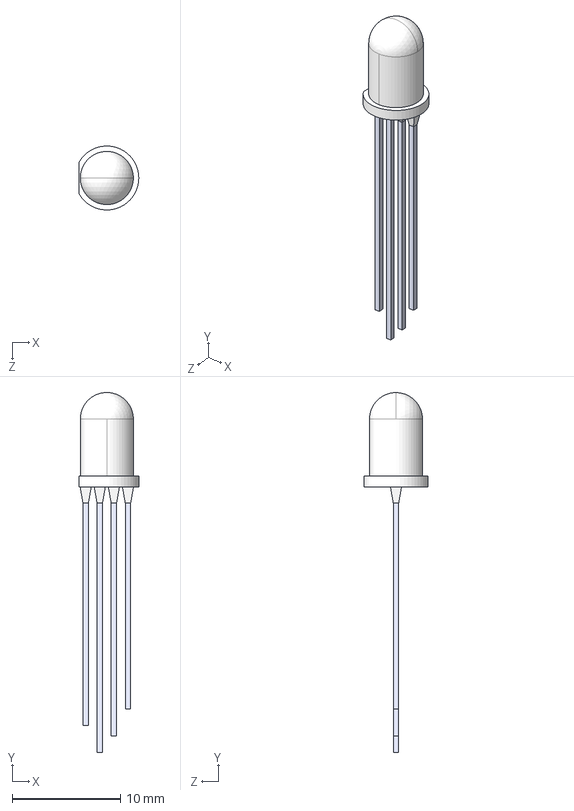
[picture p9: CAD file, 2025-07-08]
pcb/3dmodels/5mm RGB LED--3DModel-STEP-269445.STEP
5.50 x 33.2 x 5.89 mm

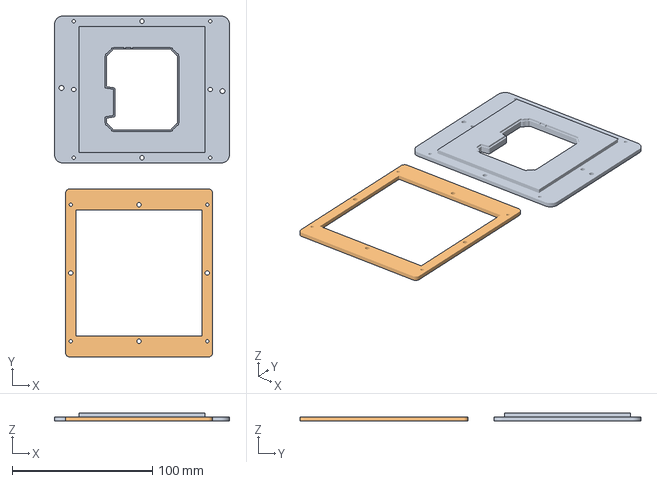
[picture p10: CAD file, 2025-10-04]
pcb/stencil/Stencil Jig/Stencil-Jig-80X80-ESPHome-Indoor-Muilti-Sensor-Rev-B.3mf
125.0 x 243.5 x 5.85 mm
Stencil Base.step
Stencil Frame.step

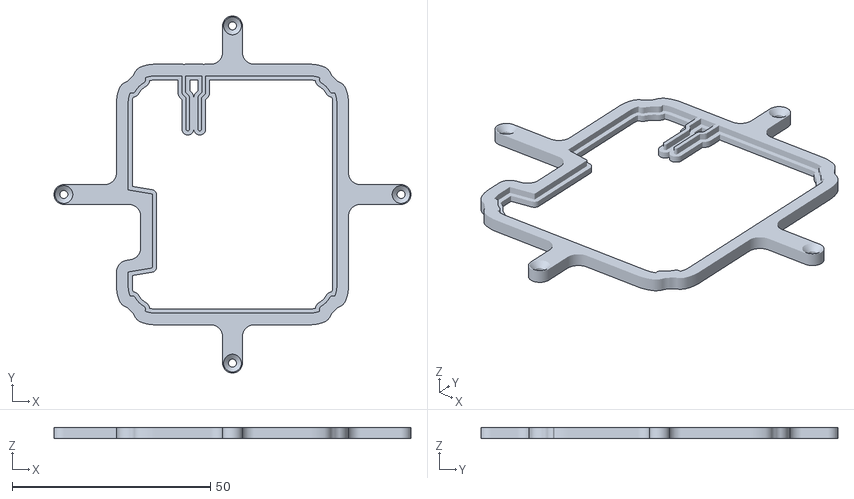
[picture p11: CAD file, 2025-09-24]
pcb/stencil/topRegister.stl
90.0 x 90.0 x 2.85

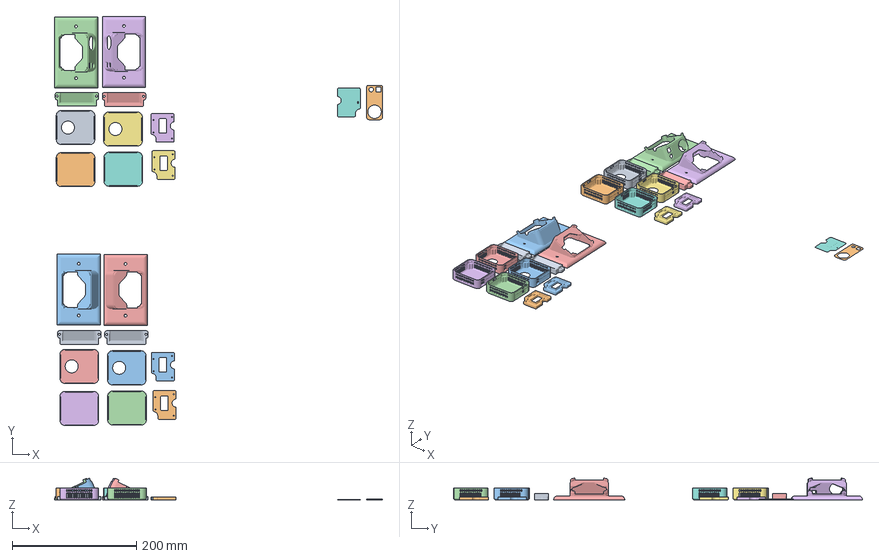
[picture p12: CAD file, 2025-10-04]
enclosure/3d-printing/Angle-Wallplate/ESPHome-Indoor-Multi-Sensor-Angle-Wallplate-Bambu-Studio.3mf
528.4 x 658.5 x 35.0 mm
ESPHome-Indoor-Multi-Sensor-Angle-Wallplate-Cap-SEN66.step x 4
ESPHome-Indoor-Multi-Sensor-Angle-Wallplate-Gasket-SEN66.step
ESPHome-Indoor-Multi-Sensor-Angle-Wallplate-Left-Facing.step
ESPHome-Indoor-Multi-Sensor-Angle-Wallplate-Left-Facing-SEN66.step
ESPHome-Indoor-Multi-Sensor-Angle-Wallplate-Right-Facing.step
ESPHome-Indoor-Multi-Sensor-Angle-Wallplate-Right-Facing-SEN66.step
ESPHome-Indoor-Multi-Sensor-Angle-Wallplate-Speaker-Enclosure.step x 4
ESPHome-Indoor-Multi-Sensor-Angle-Wallplate-Speaker-Enclosure-Gasket.step
ESPHome-Indoor-Multi-Sensor-Angle-Wallplate-Front-Body.step x 4
ESPHome-Indoor-Multi-Sensor-Angle-Wallplate-Front-Body-No-PIR.step x 4

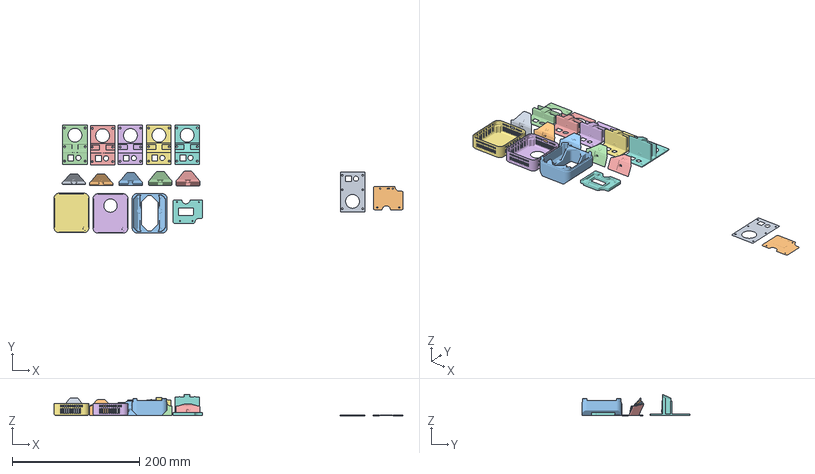
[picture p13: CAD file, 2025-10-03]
enclosure/3d-printing/Corner-Mount/ESPHome-Indoor-Multi-Sensor-Corner-Bambu-Studio.3mf
548.6 x 170.3 x 33.3 mm
ESPHome-Indoor-Multi-Sensor-Corner-Back-Mount-Gasket.step
ESPHome-Indoor-Multi-Sensor-Corner-Speaker-Gasket.step
ESPHome-Indoor-Multi-Sensor-Corner-Back-Body.step
ESPHome-Indoor-Multi-Sensor-Corner-Back-Mount-5°.step
ESPHome-Indoor-Multi-Sensor-Corner-Back-Mount-10°.step
ESPHome-Indoor-Multi-Sensor-Corner-Back-Mount-15°.step
ESPHome-Indoor-Multi-Sensor-Corner-Back-Mount-20°.step
ESPHome-Indoor-Multi-Sensor-Corner-Back-Mount-25°.step
ESPHome-Indoor-Multi-Sensor-Corner-Corner-Mount-5°.step
ESPHome-Indoor-Multi-Sensor-Corner-Corner-Mount-10°.step
ESPHome-Indoor-Multi-Sensor-Corner-Corner-Mount-15°.step
ESPHome-Indoor-Multi-Sensor-Corner-Corner-Mount-20°.step
ESPHome-Indoor-Multi-Sensor-Corner-Corner-Mount-25°.step
ESPHome-Indoor-Multi-Sensor-Corner-Front-Body.step
ESPHome-Indoor-Multi-Sensor-Corner-Front-Body-No-PIR.step
ESPHome-Indoor-Multi-Sensor-Corner-Speaker.step

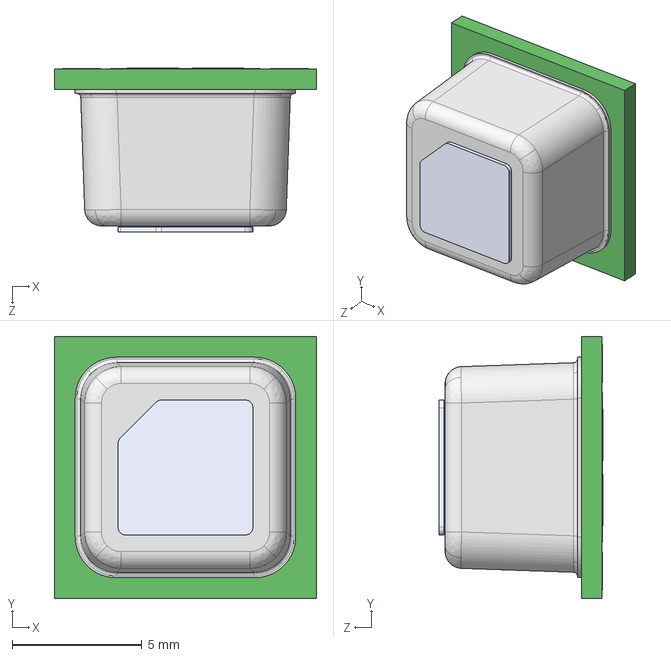
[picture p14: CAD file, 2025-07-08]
pcb/3dmodels/SCD41-D-R2--3DModel-STEP-369182.STEP
10.1 x 10.1 x 6.31 mm

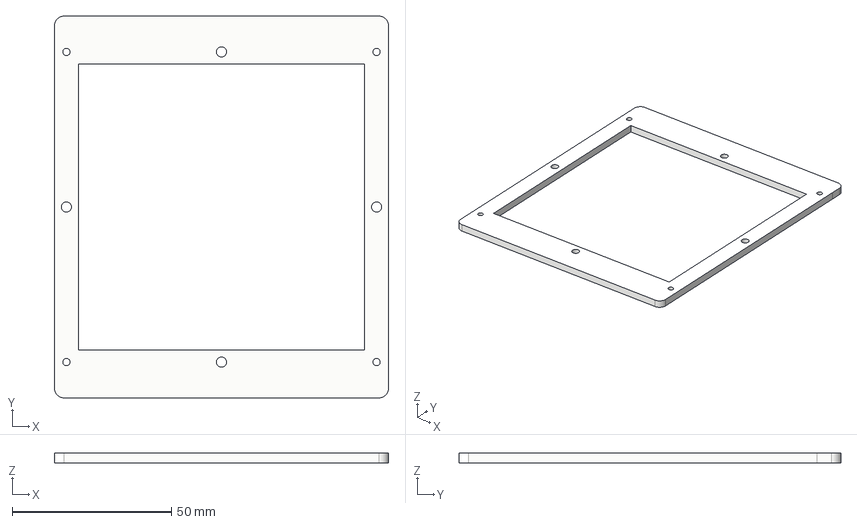
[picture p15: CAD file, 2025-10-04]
pcb/stencil/Stencil Jig/Stencil Frame.step
105.0 x 120.0 x 3.00 mm

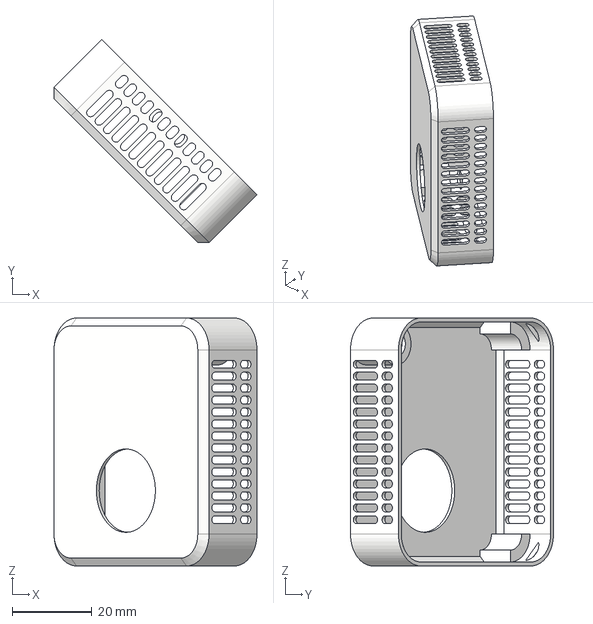
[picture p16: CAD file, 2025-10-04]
enclosure/3d-printing/Angle-Wallplate/ESPHome-Indoor-Multi-Sensor-Angle-Wallplate-Front-Body.step
50.9 x 50.9 x 62.2 mm

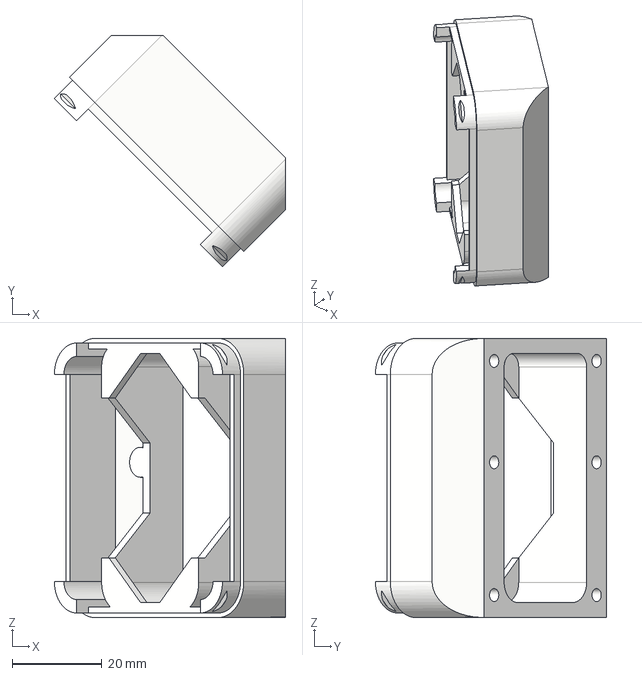
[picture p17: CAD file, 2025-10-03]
enclosure/3d-printing/Corner-Mount/ESPHome-Indoor-Multi-Sensor-Corner-Back-Body.step
51.5 x 51.5 x 62.2 mm

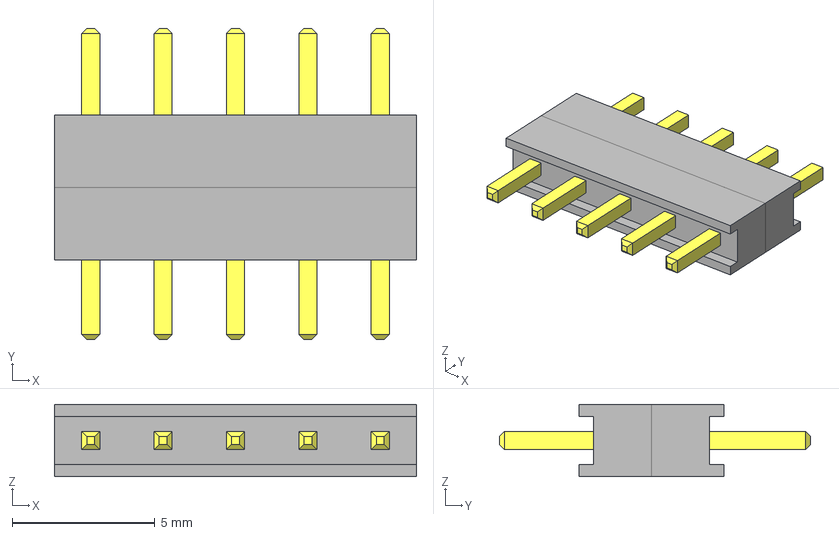
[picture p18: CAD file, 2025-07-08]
pcb/3dmodels/DW-05-07-T-S-200.stp
12.7 x 10.9 x 2.54 mm
ZW-05-07-G-S-200-110bbody
ZW-05-07-G-S-200-110_pins
ZW-05-07-G-S-200-110_top_body

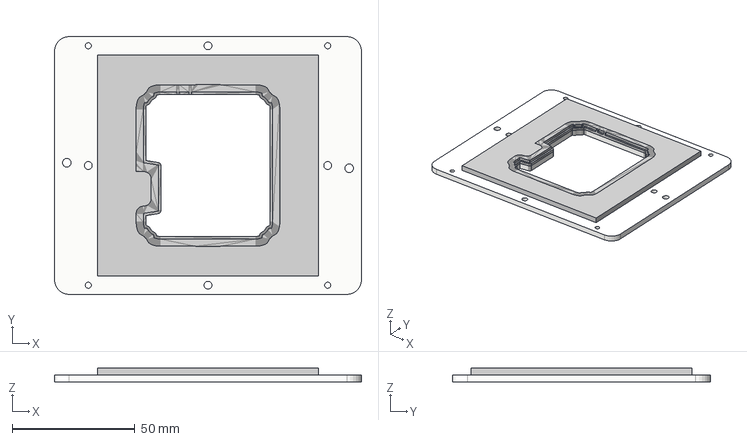
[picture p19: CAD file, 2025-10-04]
pcb/stencil/Stencil Jig/Stencil Base.step
125.0 x 105.0 x 5.85 mm

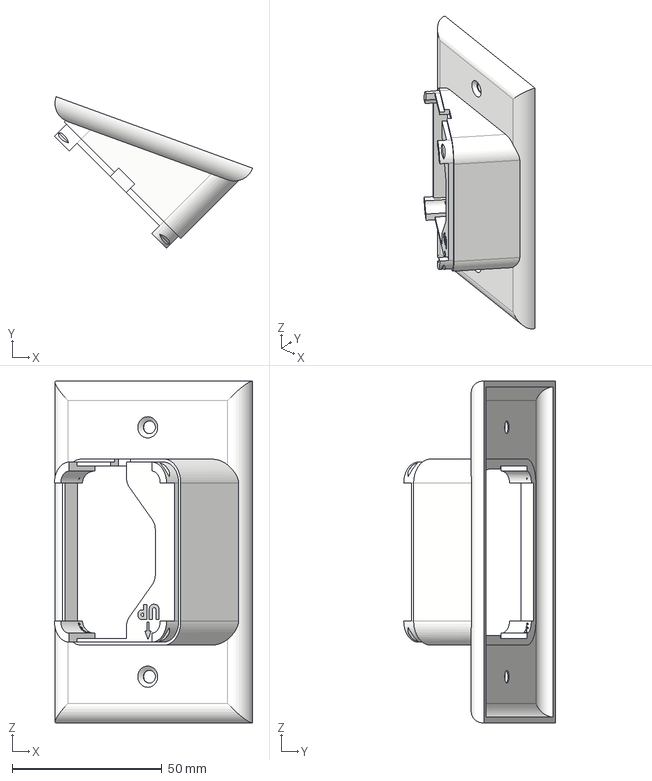
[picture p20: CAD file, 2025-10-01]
enclosure/3d-printing/Angle-Wallplate/ESPHome-Indoor-Multi-Sensor-Angle-Wallplate-Right-Facing.step
66.2 x 50.7 x 114.3 mm

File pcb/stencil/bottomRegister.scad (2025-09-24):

// Generated by SolidPython 1.1.3 on 2025-09-24 09:08:23


scale(v = 0.0000010000) {
	translate(v = [-121750001, -62649999, 0]) {
		difference() {
			linear_extrude(convexity = 10, height = 2850000) {
				polygon(points = [[94802533.6921851486, 90982472.8820157051], [94935544.1423352212, 91041887.8680582196], [95065501.8453063369, 91107685.8662379682], [95192111.3005525172, 91179716.6025123298], [95315073.8147334456, 91257810.1440656036], [95434099.2982652634, 91341782.2548880130], [95548906.9496929049, 91431434.8304206729], [95659225.9181478024, 91526556.3649176806], [95764795.9423312247, 91626922.4504240602], [95844130.6715266705, 91710045.0339231938], [95844165.1401415318, 91710079.4310309291], [95844201.2423755378, 91710112.1093896776], [95844238.8926214129, 91710142.9915110022], [95844278.0016011298, 91710172.0041657686], [95844318.4765776694, 91710199.0785578191], [95844360.2215748876, 91710224.1504871100], [95844403.1376051158, 91710247.1605019271], [95844447.1229038537, 91710268.0540398210], [95844492.0731711239, 91710286.7815570980], [95844537.8818187714, 91710303.2986461967], [95844584.4402232021, 91710317.5661410093], [95844631.6379829645, 91710329.5502098054], [95844679.3631805331, 91710339.2224353850], [95844727.5026477128, 91710346.5598825514], [95844775.9422339648, 91710351.5451523811], [95844824.5670770854, 91710354.1664235741], [95844873.2618755847, 91710354.4174804538], [95844921.9111621231, 91710352.2977277189], [95844970.3995772153, 91710347.8121917993], [95845018.6121429056, 91710340.9715090245], [95845066.4345353097, 91710331.7919003218], [95845113.7533557564, 91710320.2951328307], [95845117.1913745403, 91710319.2802351266], [95880986.2418598384, 91748845.3535129279], [95880994.4023440182, 91748854.0145835876], [95954892.0990205705, 91826355.6764137149], [95954900.3619910330, 91826364.2397639155], [95979823.7373655289, 91851887.9586543292], [95979832.1016521454, 91851896.4230714142], [96148104.5212981850, 92020168.8173734099], [96148112.9857165366, 92020177.1816587597], [96173636.7083609998, 92045100.5531893075], [96173645.2717124373, 92045108.8161584735], [96251146.9446722269, 92119006.5011619776], [96251155.6057441235, 92119014.6616448611], [96289651.8579216450, 92154855.9368740022], [96289650.7816973031, 92154858.5968651623], [96289634.7376969457, 92154904.5709787309], [96289620.9506807476, 92154951.2715916783], [96289609.4533381164, 92154998.5879754871], [96289600.2729295939, 92155046.4079416543], [96289593.4312221855, 92155094.6181076467], [96289588.9444377869, 92155143.1041657627], [96289586.8232146800, 92155191.7511541396], [96289587.0725823641, 92155240.4437293410], [96289589.6919495761, 92155289.0664398968], [96289594.6751057208, 92155337.5039999038], [96289602.0102355927, 92155385.6415625215], [96289611.6799473763, 92155433.3649921864], [96289623.6613139063, 92155480.5611352623], [96289637.9259270132, 92155527.1180883199], [96289654.4399649054, 92155572.9254634678], [96289673.1642722785, 92155617.8746500909], [96289694.0544532984, 92155661.8590723723], [96289717.0609767139, 92155704.7744419426], [96289742.1292933822, 92155746.5190052241], [96289769.1999656260, 92155786.9937846512], [96289798.2088080645, 92155826.1028133482], [96289829.0870399177, 92155863.7533626556], [96289861.7614479661, 92155899.8561620414], [96289896.1545602679, 92155934.3256107122], [96370785.5597900003, 92233148.6621551216], [96471424.1346991509, 92339050.7170594633], [96566785.9013866186, 92449728.1829086393], [96656644.5599357635, 92564918.4145968854], [96740786.8696767539, 92684348.0579193085], [96819013.1552216709, 92807733.6982603669], [96891137.7803087384, 92934782.5331577808], [96956989.5883274823, 93065193.0671386719], [97016417.2642377913, 93198666.9577525407], [97051064.2570428103, 93281881.5256736875], [97051073.7712994814, 93281903.6238728911], [97065711.6397317201, 93314806.6344122887], [97065732.2490589619, 93314850.1122976393], [97081935.8498299867, 93347010.9365541488], [97081946.9329707921, 93347032.2910730690], [97183948.2850834131, 93537912.3915367424], [97183959.8787547797, 93537933.4732414335], [97201691.6993800849, 93569277.6566269547], [97201716.3911787719, 93569318.9529459327], [97220935.3812368065, 93599773.9314542860], [97220948.4650712460, 93599794.1221641451], [97340819.6996295154, 93779989.5042112917], [97340833.2654170096, 93780009.3743118942], [97361494.9315838218, 93809504.6425095648], [97361523.4773332626, 93809543.3750678748], [97383579.9863864332, 93838010.6493172944], [97383594.9498246014, 93838029.4893546104], [97520226.6676651984, 94005872.4584227800], [97520242.0800185055, 94005890.9330230206], [97543642.3695763797, 94033264.3095667958], [97543674.5050878078, 94033300.1198975593], [97568364.4018215537, 94059516.2274288833], [97568381.1063779891, 94059533.5424305499], [97720508.7913385928, 94213470.7245998383], [97720525.9076175392, 94213487.6327186972], [97746448.2526655644, 94238485.7790897936], [97746483.6805272698, 94238518.3357711136], [97773578.4618242234, 94262240.6485020071], [97773596.7528994977, 94262256.2782189995], [97939812.4748200178, 94400862.9965702146], [97939831.1366147548, 94400878.1817243397], [97968035.6278207451, 94423269.7419789881], [97968074.0201505721, 94423298.7437012643], [97997322.9258684963, 94444307.7134299427], [97997342.6341801286, 94444321.5132104009], [98176108.0791902095, 94566314.9731022418], [98176128.1137872189, 94566328.2947541773], [98206353.7207283527, 94585906.0367037356], [98206394.7222082019, 94585931.2150582373], [98237527.0559489578, 94604032.4053676426], [98237547.9990980029, 94604044.2474956661], [98427208.7065921128, 94708295.4087295830], [98427229.9285727590, 94708306.7435884625], [98459196.9155549258, 94724889.4767197520], [98459240.1467192024, 94724910.5986827016], [98491967.7811011374, 94739936.4844327420], [98491989.7652603537, 94739946.2593103349], [98690790.4398082644, 94825490.2853141576], [98690812.6527647078, 94825499.5284767151], [98757721.0973189324, 94852401.5719383061], [98757743.5262146145, 94852410.2780354321], [98927626.4681631178, 94916011.9834223688], [98927634.4686916769, 94916014.9398638755], [98951656.9788791984, 94924775.7416594476], [98951665.0043329000, 94924778.6297551244], [99023999.6765180379, 94950461.5876028836], [99024007.7263130248, 94950464.4071425945], [99048176.1816045493, 94958814.1623959690], [99048184.2551552206, 94958816.9131746143], [99242222.3437206000, 95024006.3368971497], [99242230.4404396266, 95024009.0187146068], [99266537.8080348223, 95031945.2977230102], [99266545.9273331463, 95031947.9103841782], [99339714.5687018037, 95055148.5363236219], [99339722.7099887580, 95055151.0796384215], [99364161.9166733623, 95062671.5730196387], [99364170.0793567002, 95062674.0468030721], [99560318.9061623365, 95121206.7600597441], [99560327.0896482170, 95121209.1641318202], [99584891.0238367915, 95128311.6834910661], [99584899.2275298685, 95128314.0176769048], [99658816.6786945015, 95149005.3090050966], [99658824.9019979686, 95149007.5731348991], [99683506.4158119261, 95155690.0517044812], [99683514.6581275463, 95155692.2456135005], [99881545.9298310876, 95207500.1234557182], [99881554.1905592531, 95207502.2469843775], [99906346.1019089967, 95213762.7402255833], [99906354.3804487288, 95213764.7932194024], [99980934.6105009913, 95231922.6677938998], [99980942.9062500298, 95231924.6501034945], [100005838.0009171814, 95237761.3362703621], [100005846.3132720441, 95237763.2477515489], [100205529.5455928445, 95282785.9921193719], [100205537.8739487976, 95282787.8326330930], [100230528.9076932222, 95288199.0133044720], [100230537.2514443994, 95288200.7827168107], [100305693.4580763578, 95303804.1069822758], [100305701.8166157454, 95303805.8051645160], [100330781.5172829181, 95308789.9057379216], [100330789.8900024444, 95308791.5325665474], [100531892.6759696901, 95346976.7424670905], [100531901.0622602552, 95346978.2978237122], [100557062.1318854690, 95351533.8679711819], [100557070.5311369747, 95351535.3517426848], [100632715.2416785359, 95364565.9653303027], [100632723.6532799453, 95364567.3774087131], [100657958.7702260017, 95368693.0915017128], [100657967.1935653687, 95368694.4317843318], [100860255.4740307331, 95399997.6642844230], [100860263.9084952772, 95399998.9326737225], [100885565.7295761108, 95403693.5901675522], [100885574.1745522469, 95403694.7865712643], [100961619.3477740437, 95414137.5234339833], [100961627.8026473820, 95414138.6477650851], [100986988.9652694166, 95417401.1735489368], [100986997.4294248819, 95417402.2257256210], [101190235.7654682696, 95441787.0476753265], [101190244.2382901162, 95441788.0276210457], [101215657.3625881374, 95444617.4723299295], [101215665.8434599787, 95444618.3799733967], [101292022.9720429480, 95452461.0860373527], [101292031.4603477716, 95452461.9213125557], [101317489.1513392031, 95454857.4616044462], [101317497.6464595348, 95454858.2244505882], [101521449.4934084862, 95472296.2548866868], [101521457.9947263002, 95472296.9452482909], [101546952.8444630951,
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

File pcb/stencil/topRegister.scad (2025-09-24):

// Generated by SolidPython 1.1.3 on 2025-09-24 09:07:52


scale(v = 0.0000010000) {
	translate(v = [-121750001, -62649999, 0]) {
		difference() {
			linear_extrude(convexity = 10, height = 2850000) {
				polygon(points = [[148697468.3078148365, 90982472.8820157051], [148564457.8576647639, 91041887.8680582196], [148434500.1546936631, 91107685.8662379682], [148307890.6994474828, 91179716.6025123298], [148184928.1852665544, 91257810.1440656036], [148065902.7017347217, 91341782.2548880130], [147951095.0503070951, 91431434.8304206729], [147840776.0818521976, 91526556.3649176806], [147735206.0576687753, 91626922.4504240602], [147655871.3284733295, 91710045.0339231938], [147655836.8598584533, 91710079.4310309291], [147655800.7576244473, 91710112.1093896776], [147655763.1073786020, 91710142.9915110022], [147655723.9983988702, 91710172.0041657686], [147655683.5234223306, 91710199.0785578191], [147655641.7784250975, 91710224.1504871100], [147655598.8623948693, 91710247.1605019271], [147655554.8770961463, 91710268.0540398210], [147655509.9268288612, 91710286.7815570980], [147655464.1181812286, 91710303.2986461967], [147655417.5597767830, 91710317.5661410093], [147655370.3620170355, 91710329.5502098054], [147655322.6368194818, 91710339.2224353850], [147655274.4973523021, 91710346.5598825514], [147655226.0577660203, 91710351.5451523811], [147655177.4329228997, 91710354.1664235741], [147655128.7381244302, 91710354.4174804538], [147655080.0888378620, 91710352.2977277189], [147655031.6004227996, 91710347.8121917993], [147654983.3878570795, 91710340.9715090245], [147654935.5654646754, 91710331.7919003218], [147654888.2466442585, 91710320.2951328307], [147654884.8086254597, 91710319.2802351266], [147619015.7581401467, 91748845.3535129279], [147619007.5976559818, 91748854.0145835876], [147545109.9009794295, 91826355.6764137149], [147545101.6380089521, 91826364.2397639155], [147520178.2626344562, 91851887.9586543292], [147520169.8983478546, 91851896.4230714142], [147351897.4787018299, 92020168.8173734099], [147351889.0142834783, 92020177.1816587597], [147326365.2916390002, 92045100.5531893075], [147326356.7282875776, 92045108.8161584735], [147248855.0553277731, 92119006.5011619776], [147248846.3942558765, 92119014.6616448611], [147210350.1420783401, 92154855.9368740022], [147210351.2183026969, 92154858.5968651623], [147210367.2623030543, 92154904.5709787309], [147210381.0493192673, 92154951.2715916783], [147210392.5466618836, 92154998.5879754871], [147210401.7270703912, 92155046.4079416543], [147210408.5687777996, 92155094.6181076467], [147210413.0555621982, 92155143.1041657627], [147210415.1767853200, 92155191.7511541396], [147210414.9274176359, 92155240.4437293410], [147210412.3080504239, 92155289.0664398968], [147210407.3248942792, 92155337.5039999038], [147210399.9897643924, 92155385.6415625215], [147210390.3200526237, 92155433.3649921864], [147210378.3386861086, 92155480.5611352623], [147210364.0740729868, 92155527.1180883199], [147210347.5600351095, 92155572.9254634678], [147210328.8357277215, 92155617.8746500909], [147210307.9455466866, 92155661.8590723723], [147210284.9390232861, 92155704.7744419426], [147210259.8707066178, 92155746.5190052241], [147210232.8000343740, 92155786.9937846512], [147210203.7911919355, 92155826.1028133482], [147210172.9129600823, 92155863.7533626556], [147210140.2385520339, 92155899.8561620414], [147210105.8454397321, 92155934.3256107122], [147129216.4402099848, 92233148.6621551216], [147028577.8653008342, 92339050.7170594633], [146933216.0986133814, 92449728.1829086393], [146843357.4400642514, 92564918.4145968854], [146759215.1303232312, 92684348.0579193085], [146680988.8447783291, 92807733.6982603669], [146608864.2196912766, 92934782.5331577808], [146543012.4116725326, 93065193.0671386719], [146483584.7357622087, 93198666.9577525407], [146448937.7429571748, 93281881.5256736875], [146448928.2287005186, 93281903.6238728911], [146434290.3602682948, 93314806.6344122887], [146434269.7509410381, 93314850.1122976393], [146418066.1501700282, 93347010.9365541488], [146418055.0670292079, 93347032.2910730690], [146316053.7149165869, 93537912.3915367424], [146316042.1212452054, 93537933.4732414335], [146298310.3006199002, 93569277.6566269547], [146298285.6088212132, 93569318.9529459327], [146279066.6187632084, 93599773.9314542860], [146279053.5349287391, 93599794.1221641451], [146159182.3003704846, 93779989.5042112917], [146159168.7345829904, 93780009.3743118942], [146138507.0684161782, 93809504.6425095648], [146138478.5226667523, 93809543.3750678748], [146116422.0136135817, 93838010.6493172944], [146116407.0501753986, 93838029.4893546104], [145979775.3323348165, 94005872.4584227800], [145979759.9199814796, 94005890.9330230206], [145956359.6304236054, 94033264.3095667958], [145956327.4949122071, 94033300.1198975593], [145931637.5981784463, 94059516.2274288833], [145931620.8936220109, 94059533.5424305499], [145779493.2086614072, 94213470.7245998383], [145779476.0923824608, 94213487.6327186972], [145753553.7473344207, 94238485.7790897936], [145753518.3194727302, 94238518.3357711136], [145726423.5381757617, 94262240.6485020071], [145726405.2471005023, 94262256.2782189995], [145560189.5251799822, 94400862.9965702146], [145560170.8633852601, 94400878.1817243397], [145531966.3721792698, 94423269.7419789881], [145531927.9798494279, 94423298.7437012643], [145502679.0741314888, 94444307.7134299427], [145502659.3658198714, 94444321.5132104009], [145323893.9208098054, 94566314.9731022418], [145323873.8862127662, 94566328.2947541773], [145293648.2792716622, 94585906.0367037356], [145293607.2777917981, 94585931.2150582373], [145262474.9440510273, 94604032.4053676426], [145262454.0009019971, 94604044.2474956661], [145072793.2934078872, 94708295.4087295830], [145072772.0714272261, 94708306.7435884625], [145040805.0844450593, 94724889.4767197520], [145040761.8532807827, 94724910.5986827016], [145008034.2188988626, 94739936.4844327420], [145008012.2347396612, 94739946.2593103349], [144809211.5601917505, 94825490.2853141576], [144809189.3472352922, 94825499.5284767151], [144742280.9026810527, 94852401.5719383061], [144742258.4737854004, 94852410.2780354321], [144572375.5318368673, 94916011.9834223688], [144572367.5313083231, 94916014.9398638755], [144548345.0211207867, 94924775.7416594476], [144548336.9956671000, 94924778.6297551244], [144476002.3234819770, 94950461.5876028836], [144475994.2736869752, 94950464.4071425945], [144451825.8183954358, 94958814.1623959690], [144451817.7448447943, 94958816.9131746143], [144257779.6562793851, 95024006.3368971497], [144257771.5595603585, 95024009.0187146068], [144233464.1919651628, 95031945.2977230102], [144233456.0726668537, 95031947.9103841782], [144160287.4312981963, 95055148.5363236219], [144160279.2900112271, 95055151.0796384215], [144135840.0833266377, 95062671.5730196387], [144135831.9206432998, 95062674.0468030721], [143939683.0938376784, 95121206.7600597441], [143939674.9103517830, 95121209.1641318202], [143915110.9761632085, 95128311.6834910661], [143915102.7724701166, 95128314.0176769048], [143841185.3213055134, 95149005.3090050966], [143841177.0980020165, 95149007.5731348991], [143816495.5841880739, 95155690.0517044812], [143816487.3418724537, 95155692.2456135005], [143618456.0701689124, 95207500.1234557182], [143618447.8094407320, 95207502.2469843775], [143593655.8980910182, 95213762.7402255833], [143593647.6195512712, 95213764.7932194024], [143519067.3894990087, 95231922.6677938998], [143519059.0937499702, 95231924.6501034945], [143494163.9990828037, 95237761.3362703621], [143494155.6867279410, 95237763.2477515489], [143294472.4544071555, 95282785.9921193719], [143294464.1260511875, 95282787.8326330930], [143269473.0923067927, 95288199.0133044720], [143269464.7485556006, 95288200.7827168107], [143194308.5419236422, 95303804.1069822758], [143194300.1833842397, 95303805.8051645160], [143169220.4827170968, 95308789.9057379216], [143169212.1099975705, 95308791.5325665474], [142968109.3240303099, 95346976.7424670905], [142968100.9377397299, 95346978.2978237122], [142942939.8681145310, 95351533.8679711819], [142942931.4688630104, 95351535.3517426848], [142867286.7583214641, 95364565.9653303027], [142867278.3467200398, 95364567.3774087131], [142842043.2297739983, 95368693.0915017128], [142842034.8064346313, 95368694.4317843318], [142639746.5259692669, 95399997.6642844230], [142639738.0915047228, 95399998.9326737225], [142614436.2704238892, 95403693.5901675522], [142614427.8254477382, 95403694.7865712643], [142538382.6522259712, 95414137.5234339833], [142538374.1973526180, 95414138.6477650851], [142513013.0347305834, 95417401.1735489368], [142513004.5705751181, 95417402.2257256210], [142309766.2345317304, 95441787.0476753265], [142309757.7617098689, 95441788.0276210457], [142284344.6374118626, 95444617.4723299295], [142284336.1565400362, 95444618.3799733967], [142207979.0279570520, 95452461.0860373527], [142207970.5396522284, 95452461.9213125557], [142182512.8486607969, 95454857.4616044462],
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

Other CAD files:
pcb/stencil/bottomRegister.stl
enclosure/3d-printing/Corner-Mount/ESPHome-Indoor-Multi-Sensor-Corner-Back-Mount-Gasket.step
enclosure/3d-printing/Angle-Wallplate/ESPHome-Indoor-Multi-Sensor-Angle-Wallplate-Left-Facing-SEN66.step
enclosure/3d-printing/Corner-Mount/ESPHome-Indoor-Multi-Sensor-Corner-Back-Mount-5°.step
enclosure/3d-printing/Angle-Wallplate/ESPHome-Indoor-Multi-Sensor-Angle-Wallplate-Cap-SEN66.step
enclosure/3d-printing/Angle-Wallplate/ESPHome-Indoor-Multi-Sensor-Angle-Wallplate-Gasket-SEN66.step
enclosure/3d-printing/Angle-Wallplate/ESPHome-Indoor-Multi-Sensor-Angle-Wallplate-Left-Facing.step
enclosure/3d-printing/Angle-Wallplate/ESPHome-Indoor-Multi-Sensor-Angle-Wallplate-Right-Facing-SEN66.step
enclosure/3d-printing/Angle-Wallplate/ESPHome-Indoor-Multi-Sensor-Angle-Wallplate-Speaker-Enclosure-Gasket.step
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

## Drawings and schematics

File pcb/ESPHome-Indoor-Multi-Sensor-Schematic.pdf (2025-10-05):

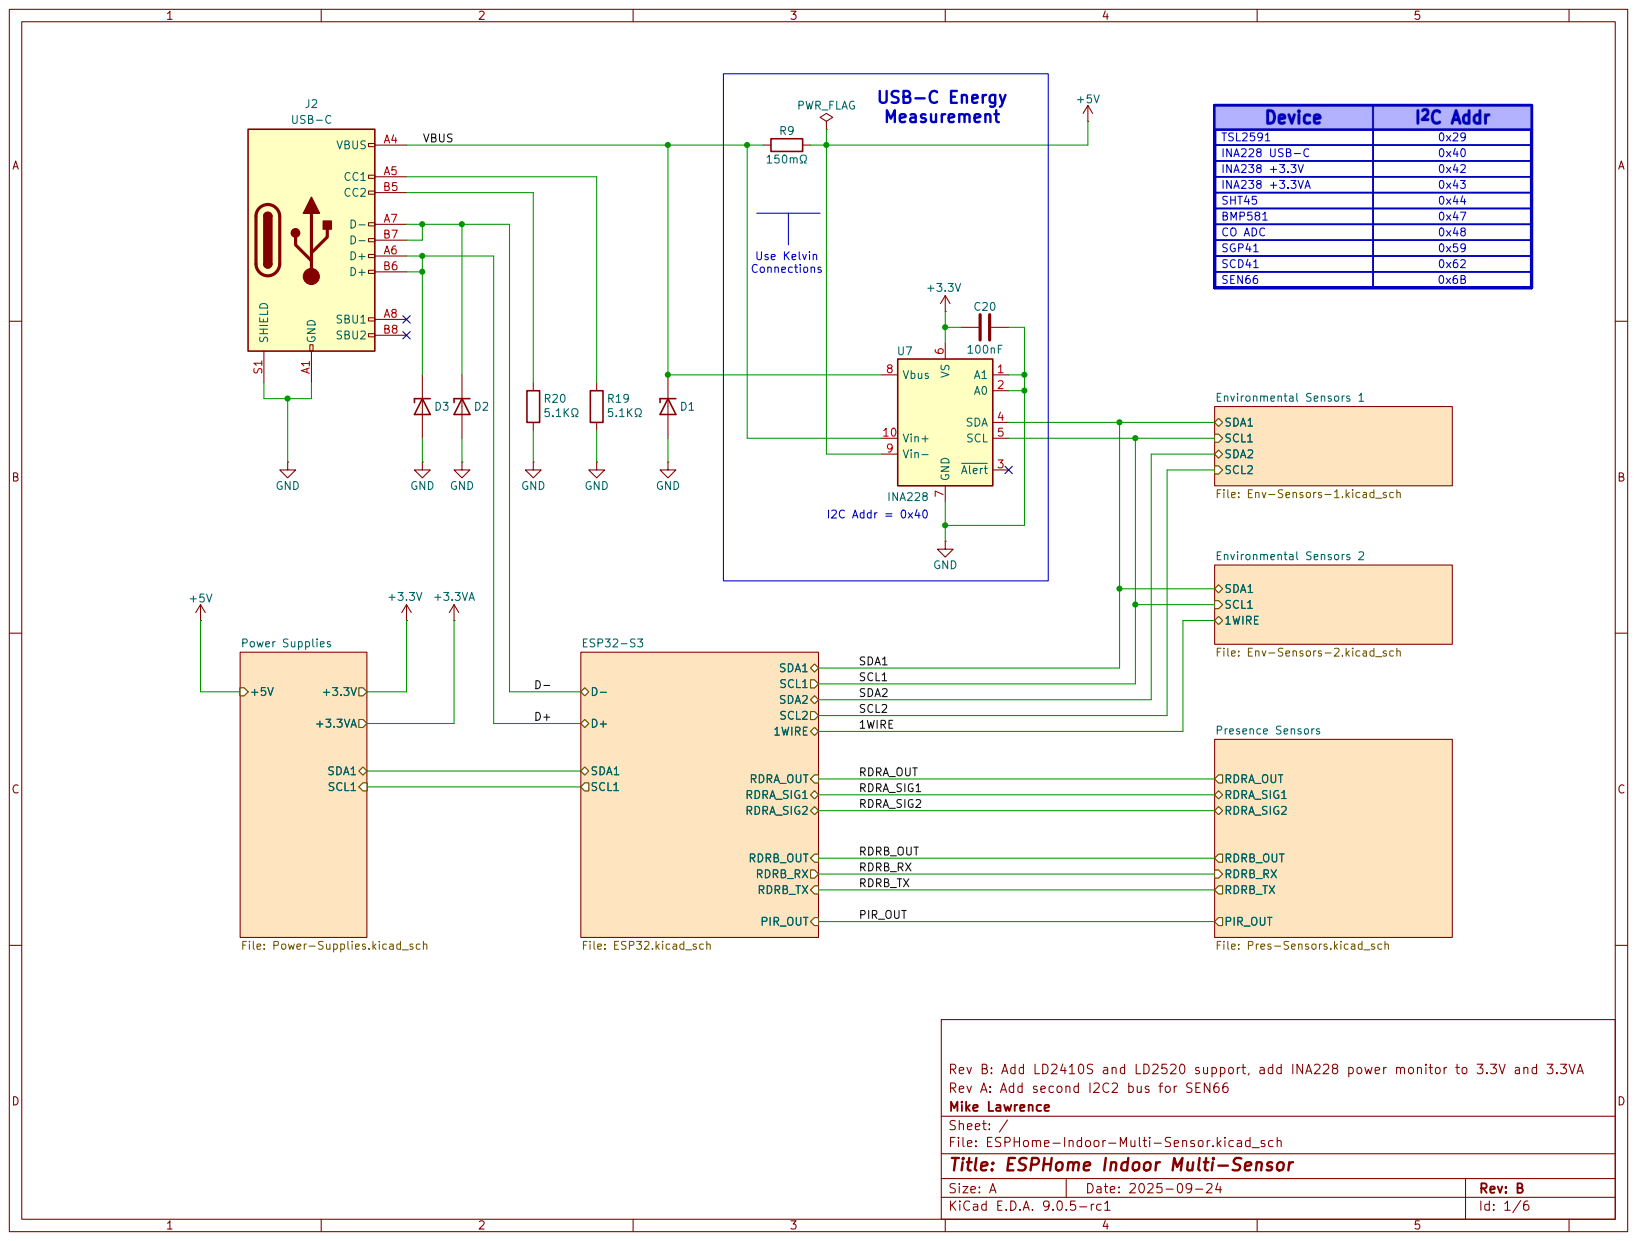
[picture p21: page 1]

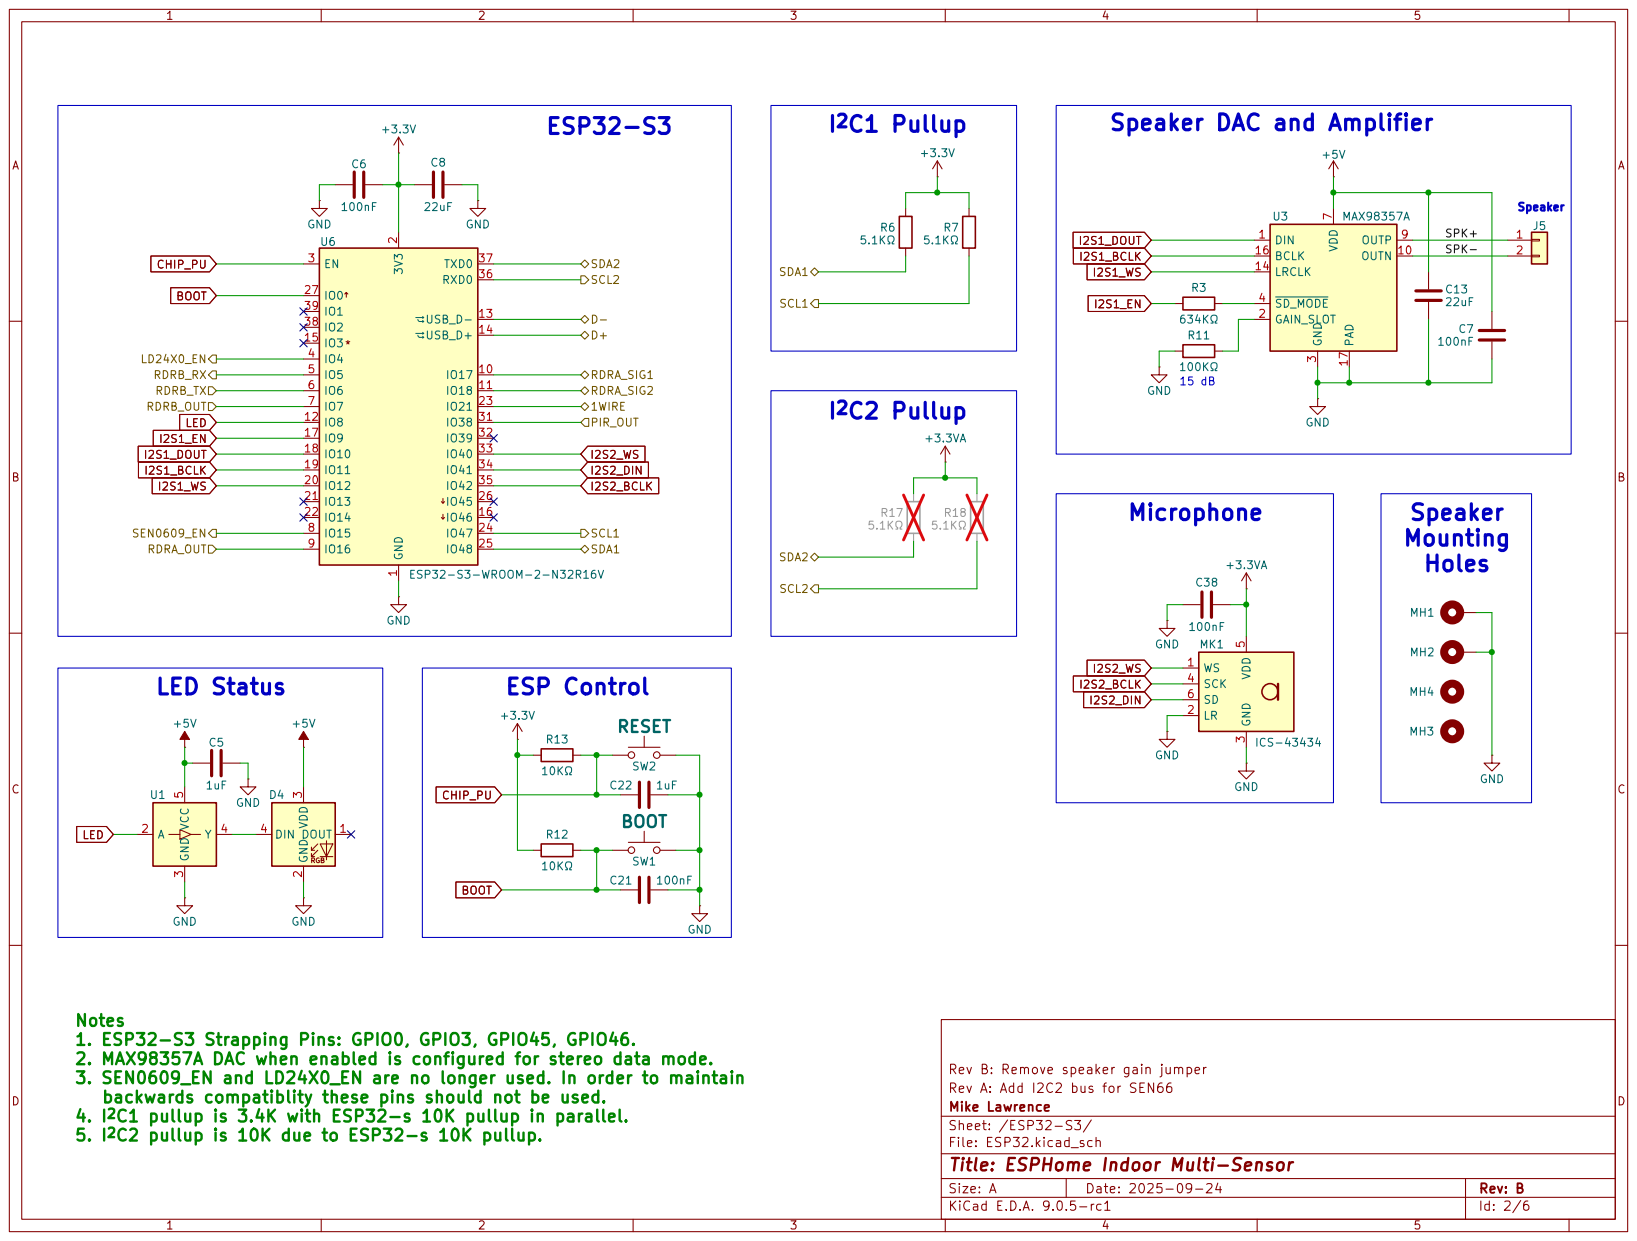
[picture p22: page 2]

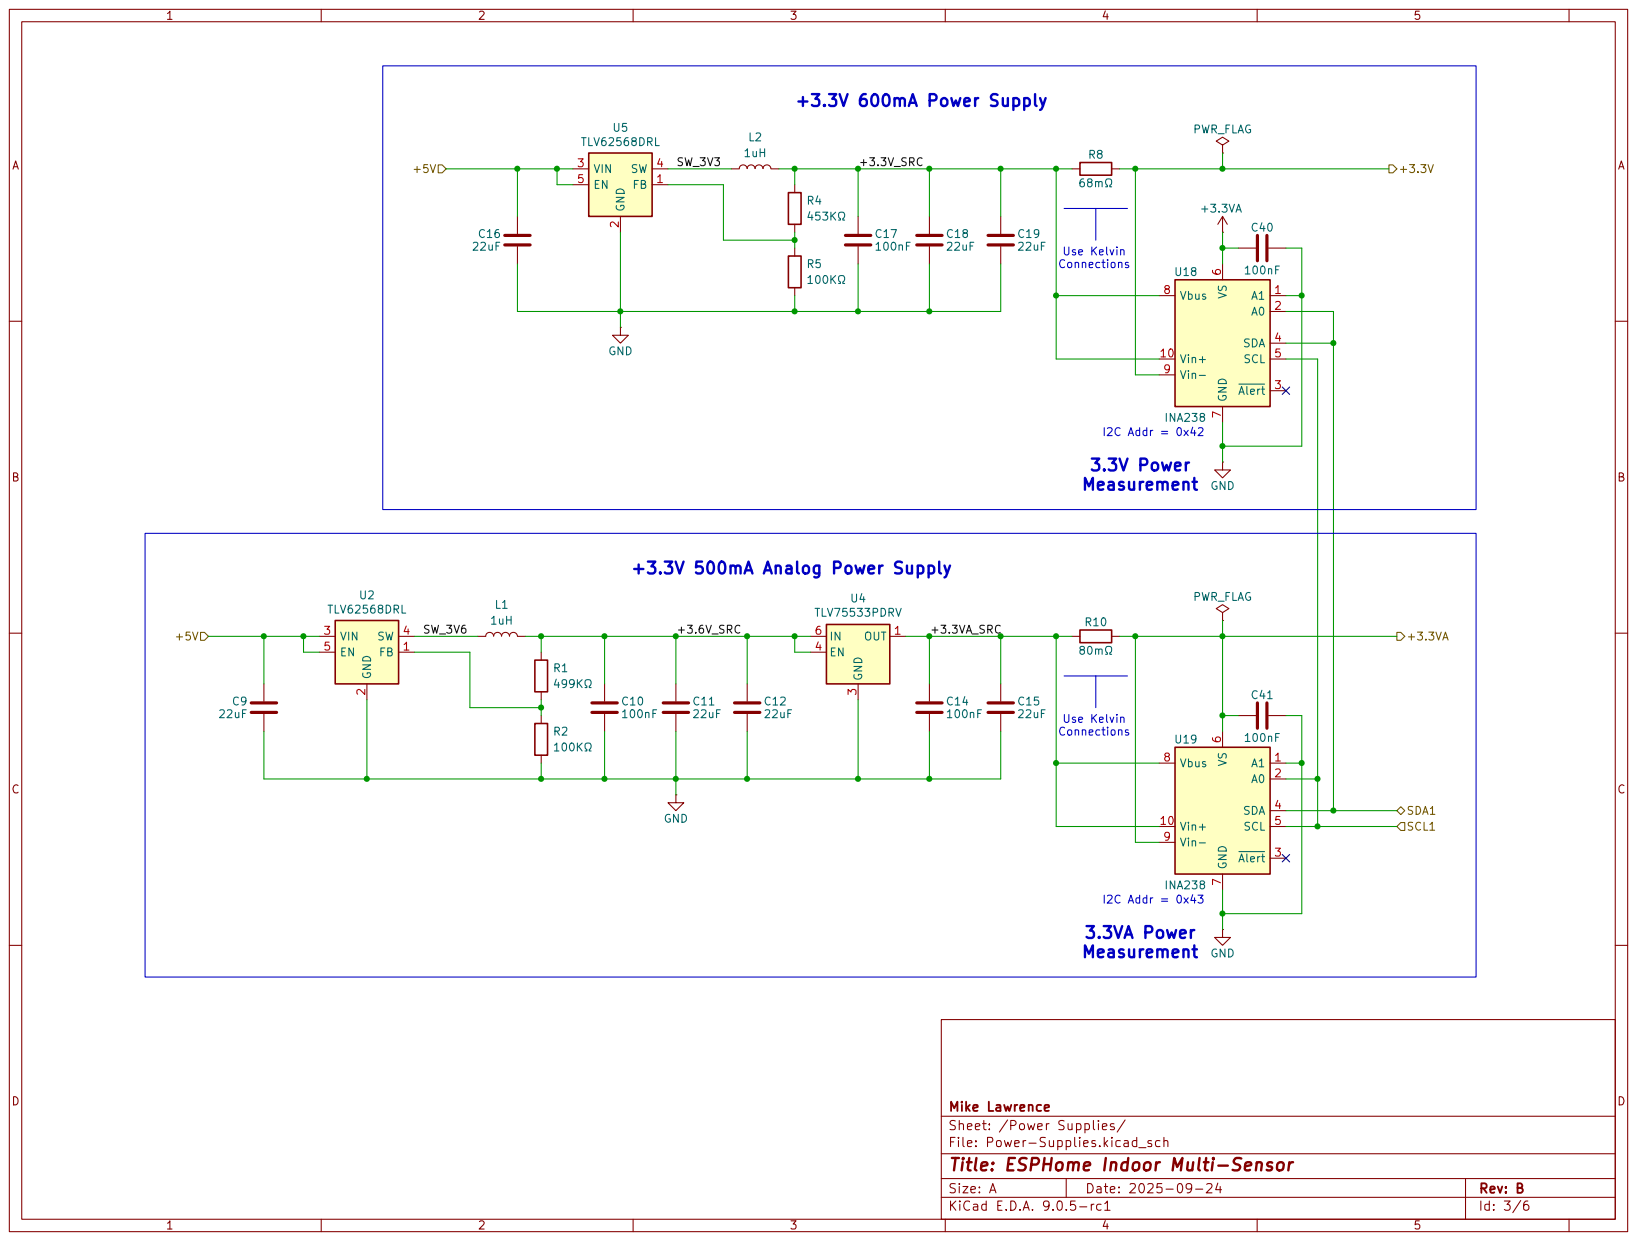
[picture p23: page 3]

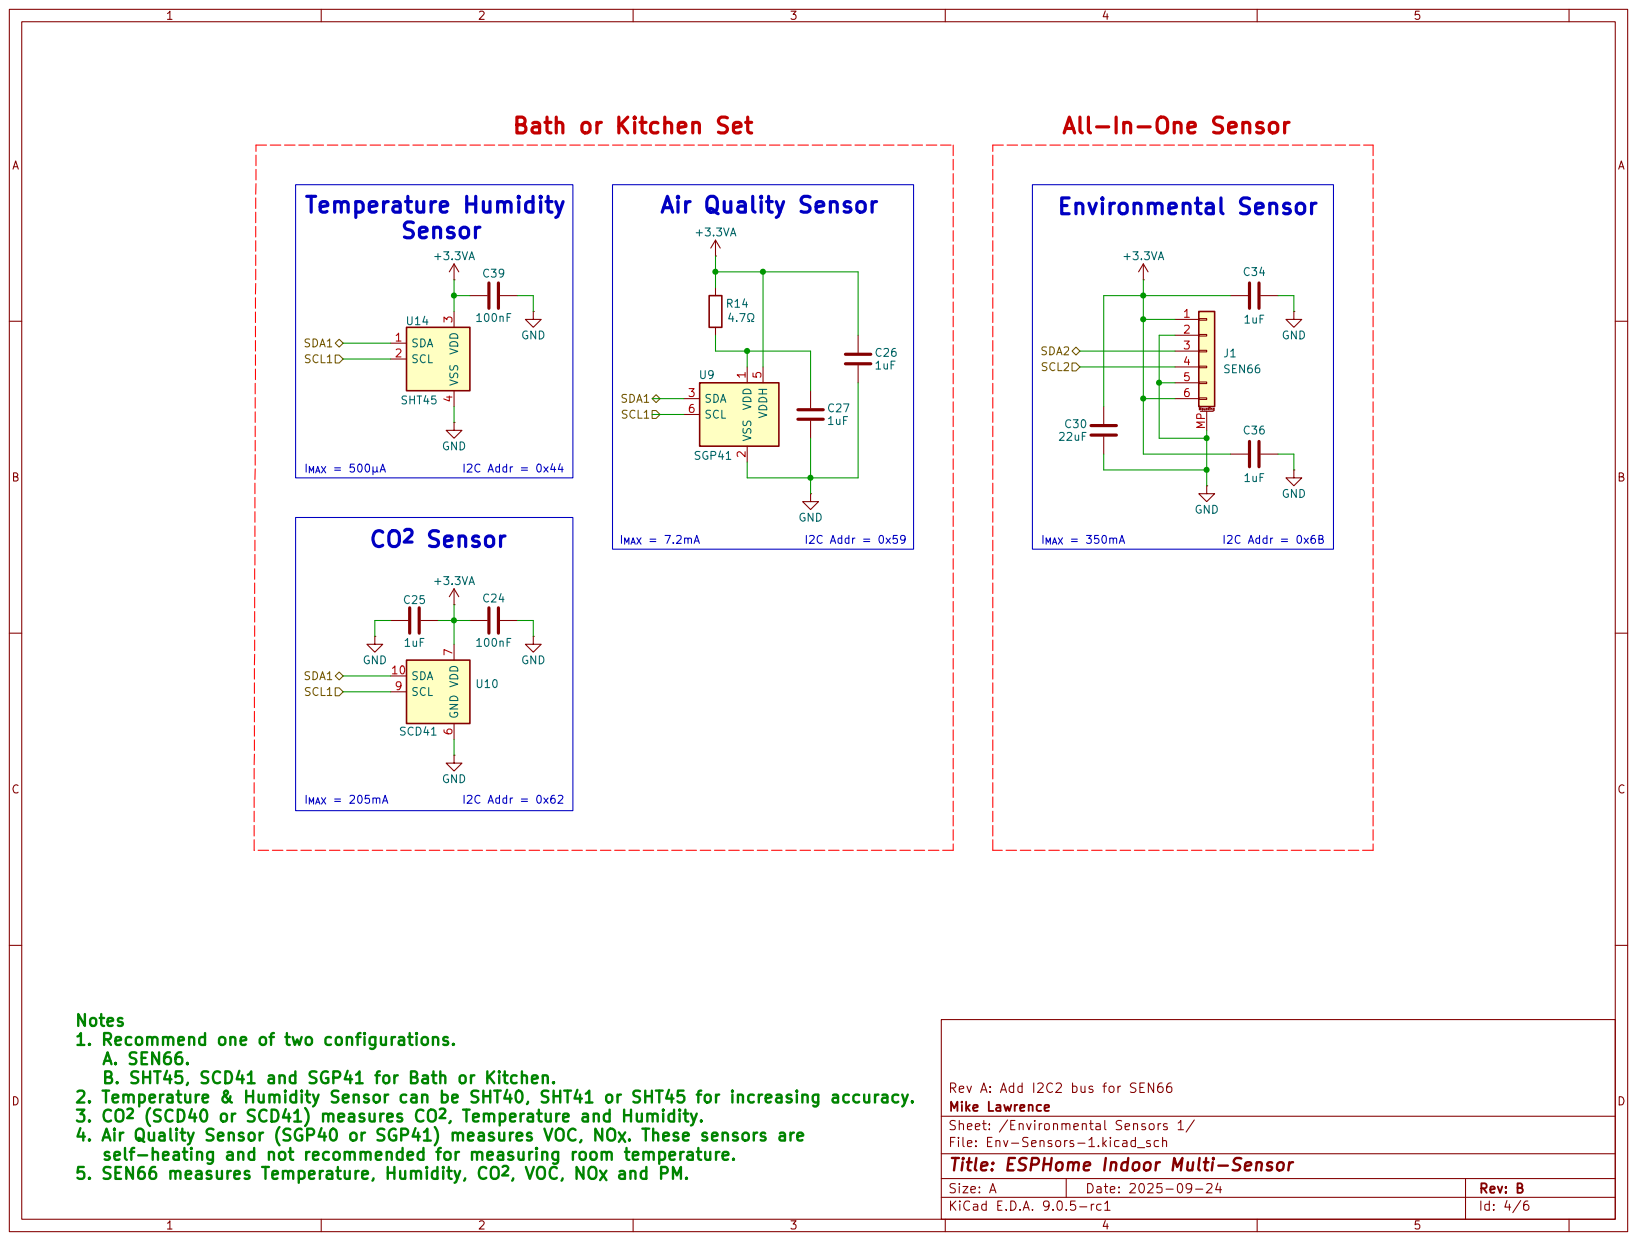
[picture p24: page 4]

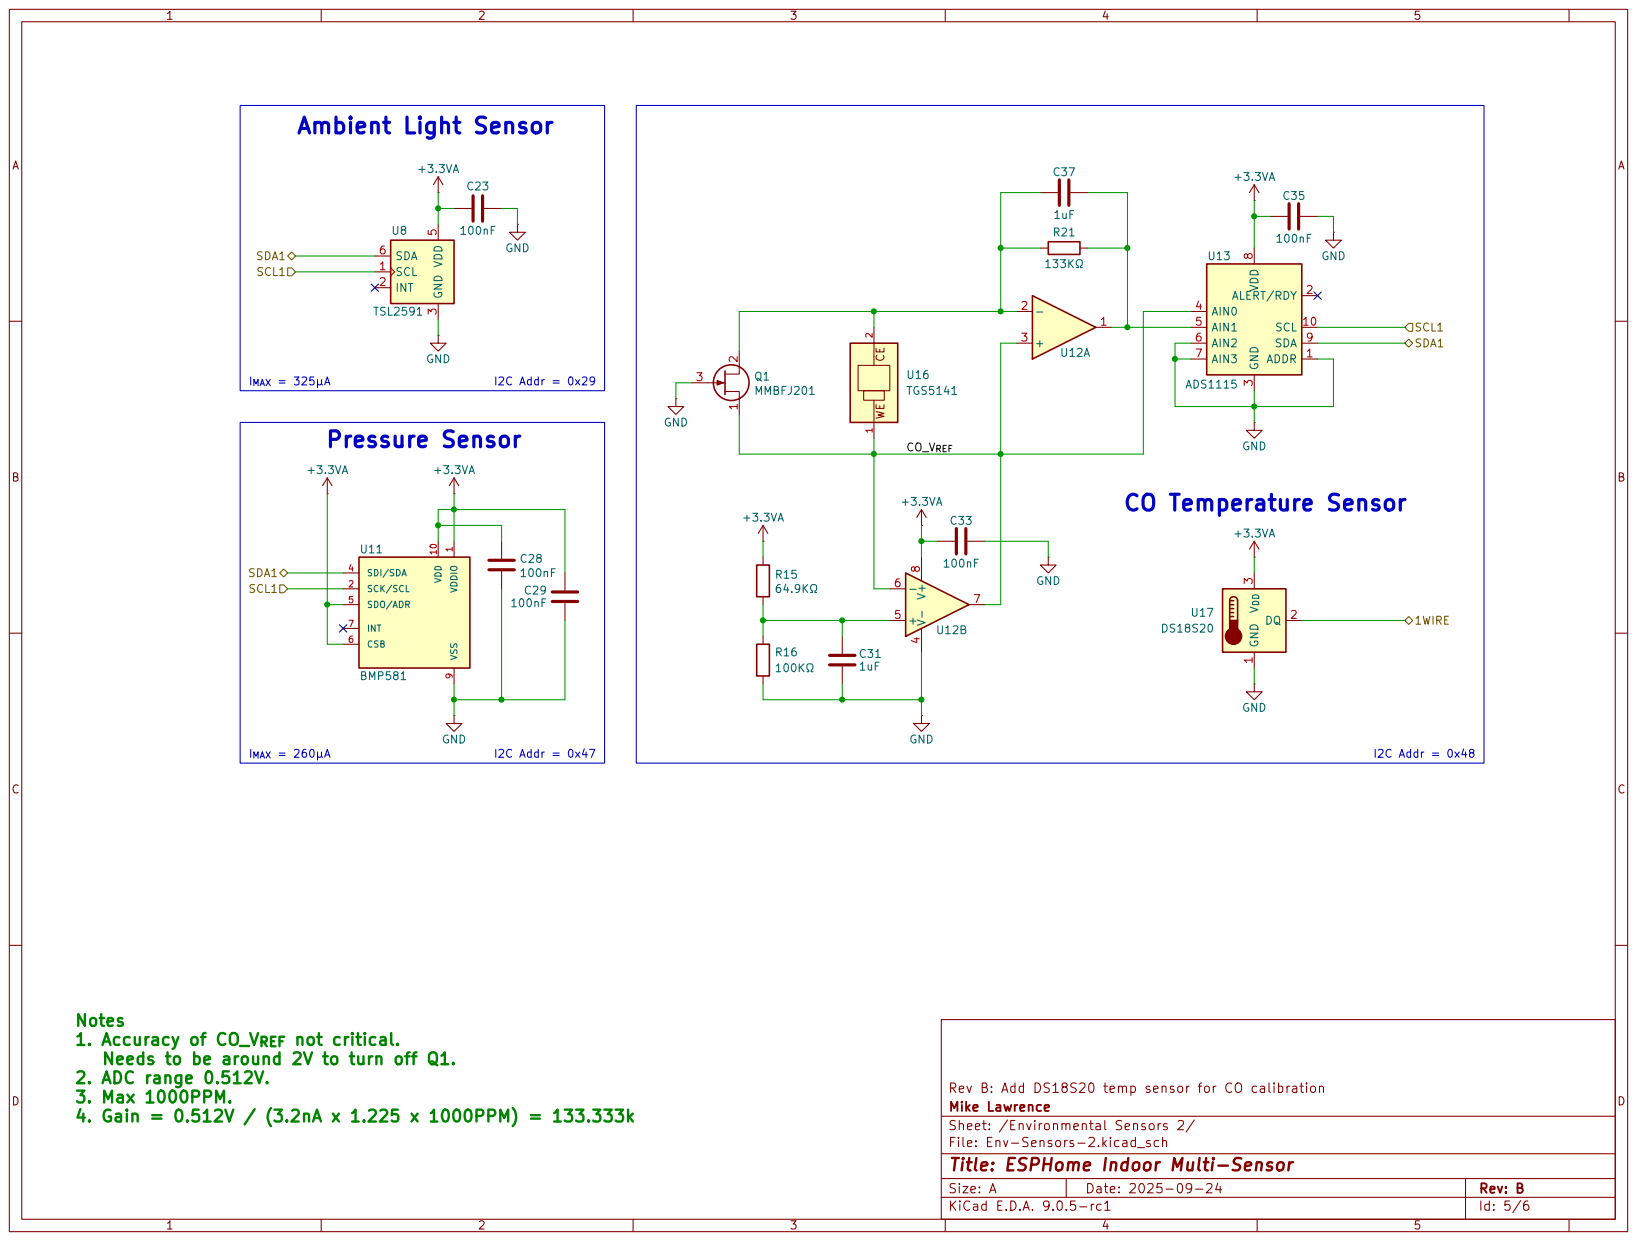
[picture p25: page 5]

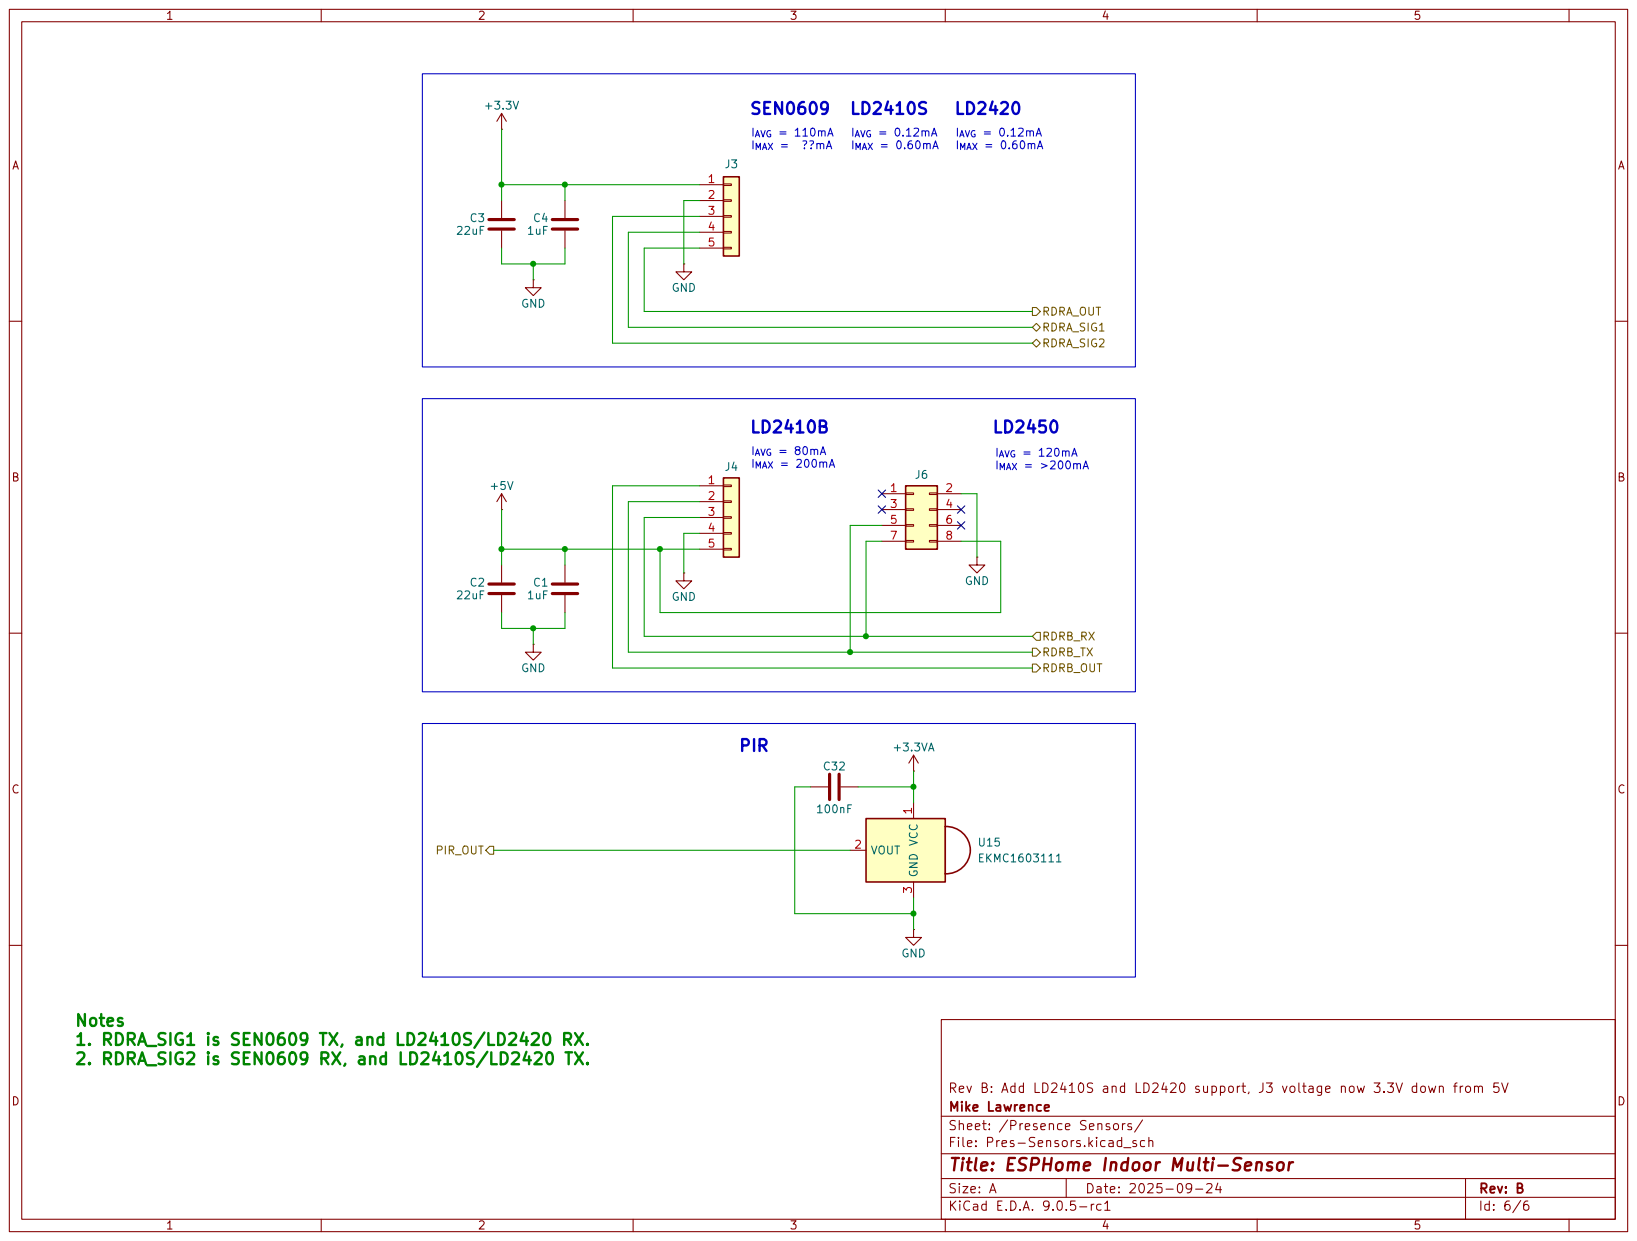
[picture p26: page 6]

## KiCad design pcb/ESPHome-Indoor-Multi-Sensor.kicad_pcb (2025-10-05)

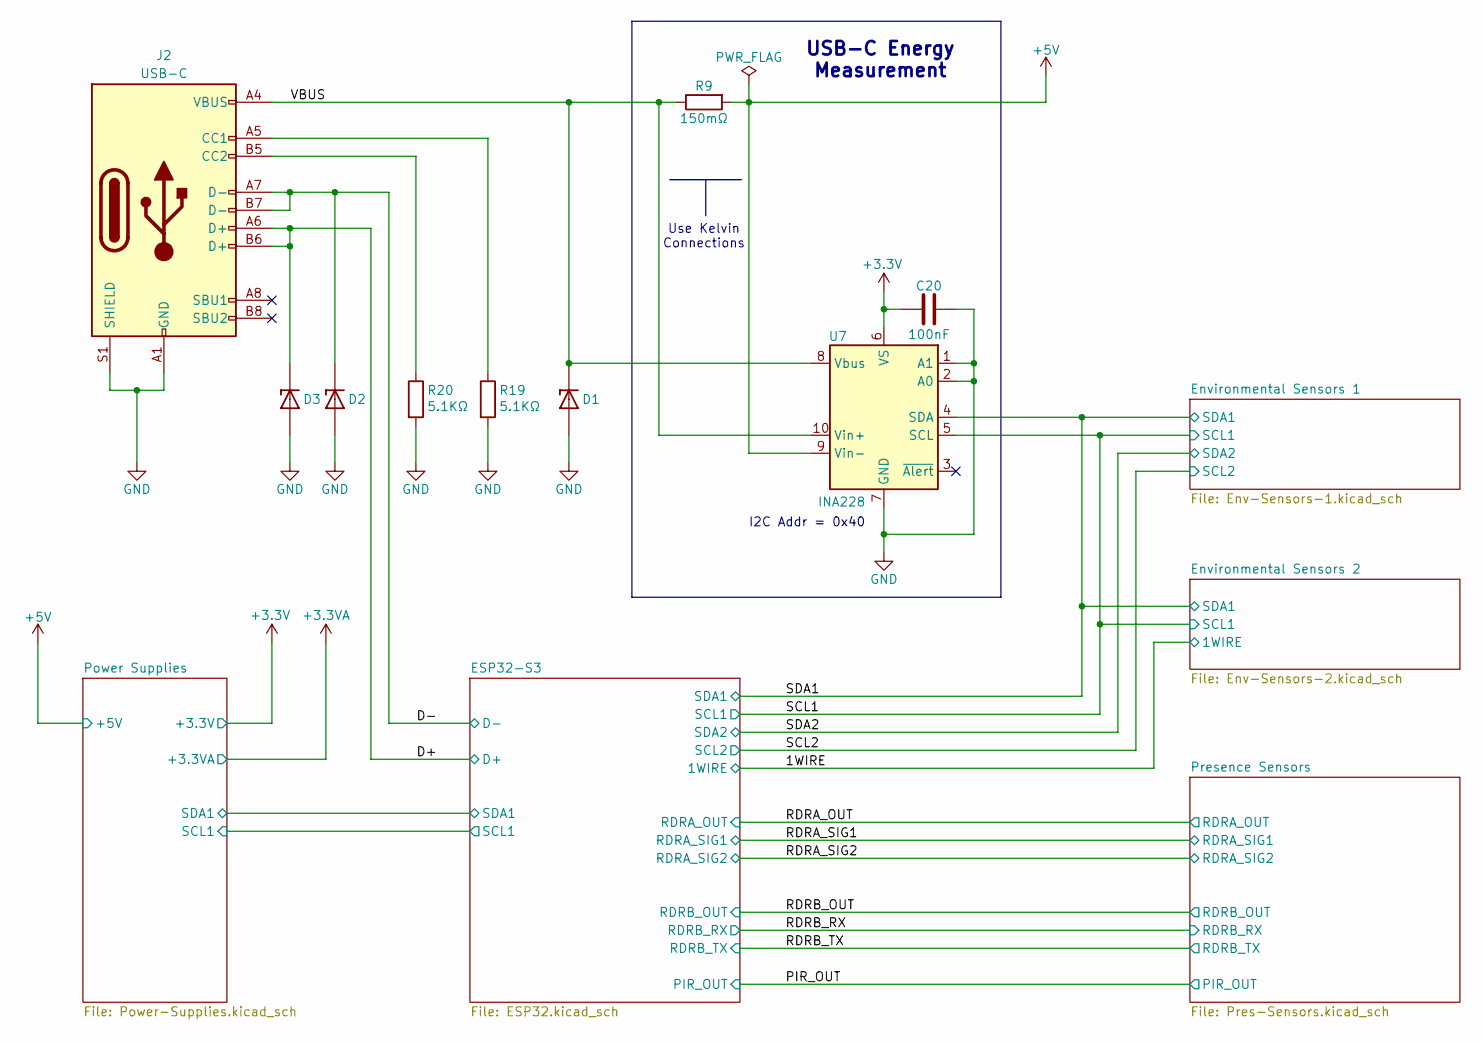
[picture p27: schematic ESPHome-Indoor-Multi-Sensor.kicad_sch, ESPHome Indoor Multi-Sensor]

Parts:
C20: 100nF; C_0402_1005Metric; Part Number CL05B104KB54PNC
D1, D2, D3: ESDA8P80-1U1M; TVS_ESDA25P35-1U1M; Part Number ESDA8P80-1U1M
J2: USB-C; USB_C_Receptacle_HRO_TYPE-C-31-M-12; Part Number 1332645
R9: 150mΩ; R_0805_2012Metric; Part Number WSL0805R1500FEA18
R19, R20: 5.1KΩ; R_0402_1005Metric; Part Number CRCW04025K10FKED
U7: INA228; VSSOP-10_3x3mm_P0.5mm; Part Number INA228AIDGSR

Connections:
+3.3V: C20.2, U7.6 (VS); also elsewhere on the board
+5V: R9.2, U7.9 (Vin-); also elsewhere on the board
/D+: D3.C, J2.A6 (D+), J2.B6 (D+); also elsewhere on the board
/D-: D2.C, J2.A7 (D-), J2.B7 (D-); also elsewhere on the board
/SCL1: U7.5 (SCL); also elsewhere on the board
/SDA1: U7.4 (SDA); also elsewhere on the board
/VBUS: D1.C, J2.A4 (VBUS), J2.A9 (VBUS), J2.B4 (VBUS), J2.B9 (VBUS), R9.1, U7.8 (Vbus), U7.10 (Vin+)
GND: C20.1, D1.A, D2.A, D3.A, J2.A1 (GND), J2.A12 (GND), J2.B1 (GND), J2.B12 (GND), J2.S1 (SHIELD), R19.2, R20.2, U7.1 (A1), U7.2 (A0), U7.7 (GND); also elsewhere on the board
unnamed: J2.A5 (CC1), R19.1
unnamed: J2.B5 (CC2), R20.1

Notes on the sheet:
I2C Addr = 0x40
USB-C Energy Measurement
Use Kelvin Connections

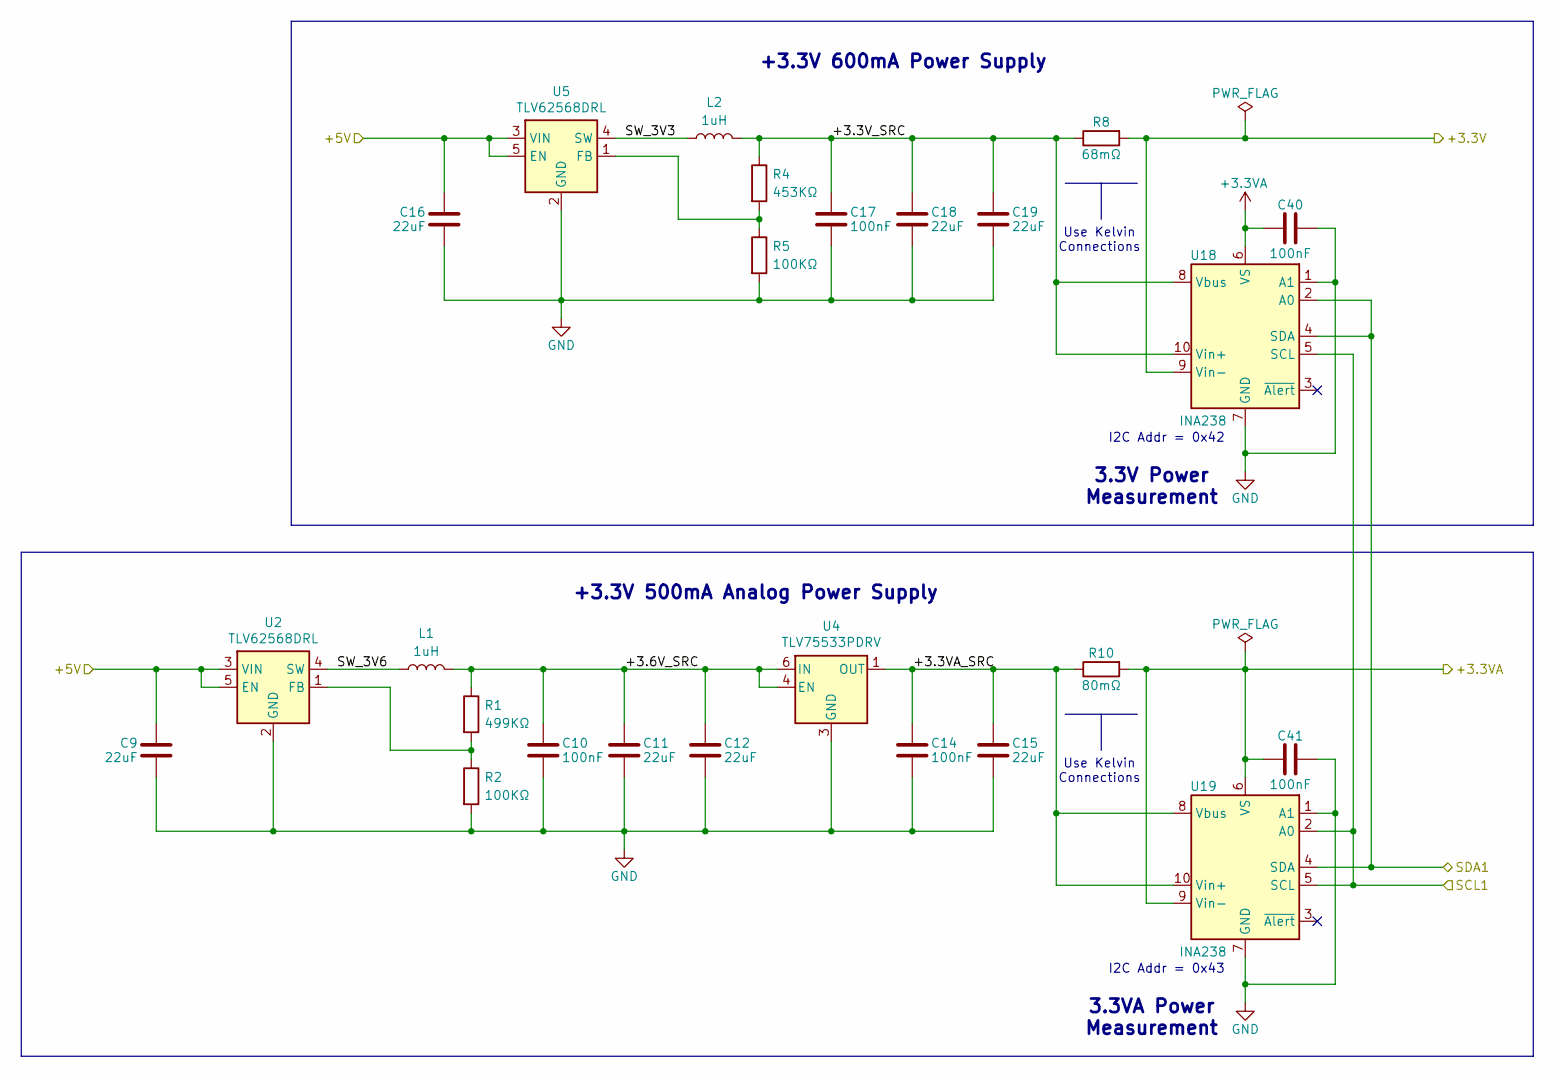
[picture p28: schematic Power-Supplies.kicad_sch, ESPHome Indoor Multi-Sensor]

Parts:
C9, C11, C12, C15, C16, C18, C19: 22uF; C_0603_1608Metric; Part Number GRM188R60J226MEA0D
C10, C14, C17, C40, C41: 100nF; C_0402_1005Metric; Part Number CL05B104KB54PNC
L1, L2: 1uH; L_1008_2520Metric; Part Number DFE252012F-1R0M=P2
R1: 499KΩ; R_0402_1005Metric; Part Number CRCW0402499KFKED
R2, R5: 100KΩ; R_0402_1005Metric; Part Number CRCW0402100KFKED
R4: 453KΩ; R_0402_1005Metric; Part Number CRCW0402453KFKED
R8: 68mΩ; R_0603_1608Metric; Part Number WSLP0603R0680FEA
R10: 80mΩ; R_0603_1608Metric; Part Number WSLP0603R0800FEB
U2, U5: TLV62568DRL; SOT50P160X60-6N; Part Number TLV62568DRL
U4: TLV75533PDRV; VREG_TLV75533PDRVR; Part Number TLV75533PDRV
U18, U19: INA238; VSSOP-10_3x3mm_P0.5mm; Part Number INA238AIDGSR

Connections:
+3.3V: R8.2, U18.9 (Vin-); also elsewhere on the board
+3.3VA: C40.2, C41.2, R10.2, U18.6 (VS), U19.6 (VS), U19.9 (Vin-); also elsewhere on the board
+5V: C9.1, C16.1, U2.3 (VIN), U2.5 (EN), U5.3 (VIN), U5.5 (EN); also elsewhere on the board
/Power Supplies/+3.3VA_SRC: C14.2, C15.1, R10.1, U4.1 (OUT), U19.8 (Vbus), U19.10 (Vin+)
/Power Supplies/+3.3V_SRC: C17.2, C18.1, C19.1, L2.2, R4.1, R8.1, U18.8 (Vbus), U18.10 (Vin+)
/Power Supplies/+3.6V_SRC: C10.2, C11.1, C12.1, L1.2, R1.1, U4.4 (EN), U4.6 (IN)
/Power Supplies/SW_3V3: L2.1, U5.4 (SW)
/Power Supplies/SW_3V6: L1.1, U2.4 (SW)
/SCL1: U18.5 (SCL), U19.2 (A0), U19.5 (SCL); also elsewhere on the board
/SDA1: U18.2 (A0), U18.4 (SDA), U19.4 (SDA); also elsewhere on the board
GND: C9.2, C10.1, C11.2, C12.2, C14.1, C15.2, C16.2, C17.1, C18.2, C19.2, C40.1, C41.1, R2.2, R5.2, U2.2 (GND), U4.3 (GND), U4.7 (GND), U5.2 (GND), U18.1 (A1), U18.7 (GND), U19.1 (A1), U19.7 (GND); also elsewhere on the board
unnamed: R1.2, R2.1, U2.1 (FB)
unnamed: R4.2, R5.1, U5.1 (FB)

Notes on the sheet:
+3.3V 600mA Power Supply
3.3VA Power Measurement
I2C Addr = 0x43
+3.3V 500mA Analog Power Supply
3.3V Power Measurement
Use Kelvin Connections
I2C Addr = 0x42

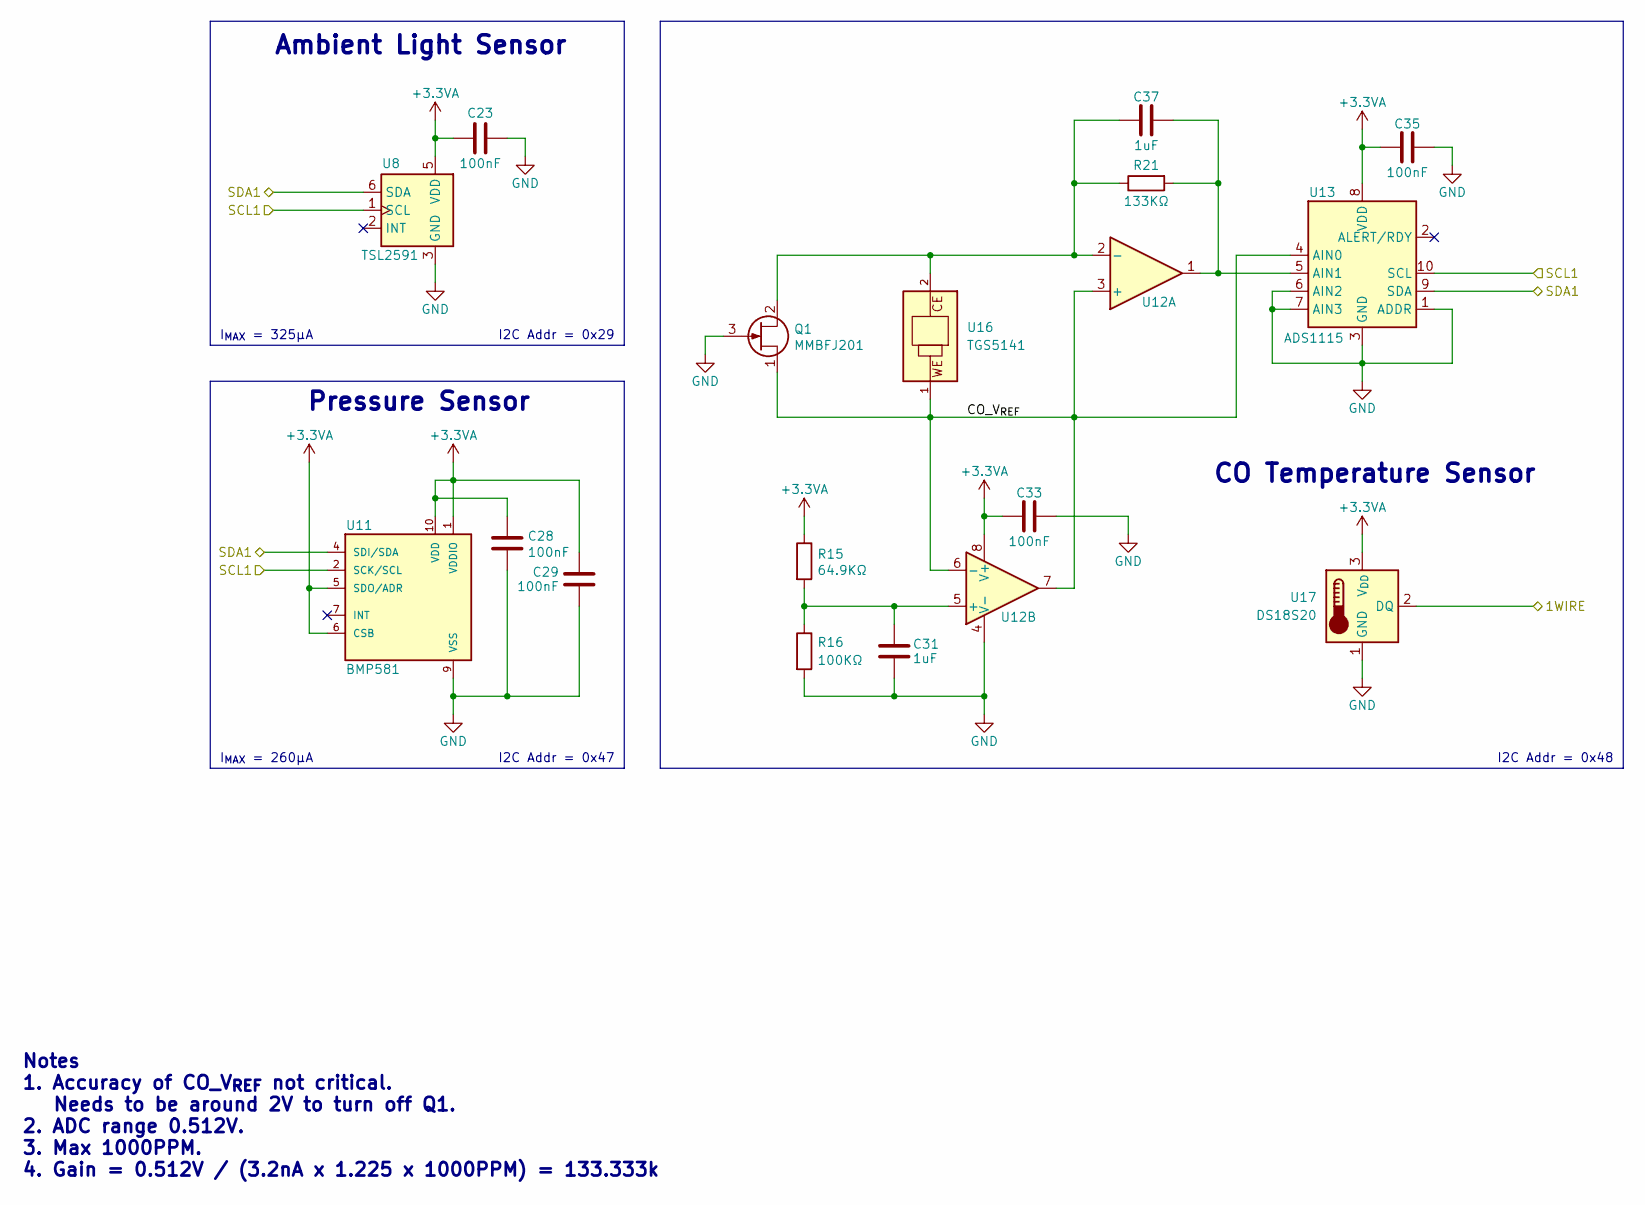
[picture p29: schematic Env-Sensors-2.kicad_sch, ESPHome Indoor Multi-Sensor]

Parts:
C23, C28, C29, C33, C35: 100nF; C_0402_1005Metric; Part Number CL05B104KB54PNC
C31, C37: 1uF; C_0402_1005Metric; Part Number CL05A105KA5NQNC
Q1: MMBFJ201; SOT-23; Part Number MMBFJ201
R15: 64.9KΩ; R_0402_1005Metric; Part Number CRCW040264K9FKED
R16: 100KΩ; R_0402_1005Metric; Part Number CRCW0402100KFKED
R21: 133KΩ; R_0402_1005Metric; Part Number CRCW0402133KFKED
U8: TSL2591; AMS_TSL25911FN; Part Number TSL2591
U11: BMP581; Part Number BMP581
U12: MCP6042; MSOP-8_3x3mm_P0.65mm; Part Number MCP6042T-I/MS
U13: ADS1115; TSSOP-10_3x3mm_P0.5mm; Part Number ADS1115IDGS
U16: TGS5141; TGS-5141; Part Number TGS5141-P00
U17: DS18S20; TO-92_Inline; Part Number DS18S20+

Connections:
+3.3VA: C23.2, C28.1, C29.1, C33.1, C35.1, R15.1, U8.5 (VDD), U11.1 (VDDIO), U11.5 (SDO/ADR), U11.6 (CSB), U11.10 (VDD), U12.8 (V+), U13.8 (VDD), U17.3 (V_{DD}); also elsewhere on the board
/1WIRE: U17.2 (DQ); also elsewhere on the board
/Environmental Sensors 2/CO_V_{REF}: Q1.1 (D), U12.3 (+), U12.6 (-), U12.7, U13.4 (AIN0), U16.1 (WE)
/SCL1: U8.1 (SCL), U11.2 (SCK/SCL), U13.10 (SCL); also elsewhere on the board
/SDA1: U8.6 (SDA), U11.4 (SDI/SDA), U13.9 (SDA); also elsewhere on the board
GND: C23.1, C28.2, C29.2, C31.2, C33.2, C35.2, Q1.3 (G), R16.2, U8.3 (GND), U11.3 (VSS), U11.8 (VSS), U11.9 (VSS), U12.4 (V-), U13.1 (ADDR), U13.3 (GND), U13.6 (AIN2), U13.7 (AIN3), U17.1 (GND); also elsewhere on the board
unnamed: C37.1, Q1.2 (S), R21.1, U12.2 (-), U16.2 (CE)
unnamed: C31.1, R15.2, R16.1, U12.5 (+)
unnamed: C37.2, R21.2, U12.1, U13.5 (AIN1)

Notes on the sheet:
I_{MAX} = 260µA
CO Temperature Sensor
I2C Addr = 0x29
I2C Addr = 0x48
Notes 1. Accuracy of CO_V_{REF} not critical. Needs to be around 2V to turn off Q1. 2. ADC range 0.512V. 3. Max 1000PPM. 4. Gain = 0.512V / (3.2nA x 1.225 x 1000PPM) = 133.333k
Ambient Light Sensor
I_{MAX} = 325µA
I2C Addr = 0x47
Pressure Sensor

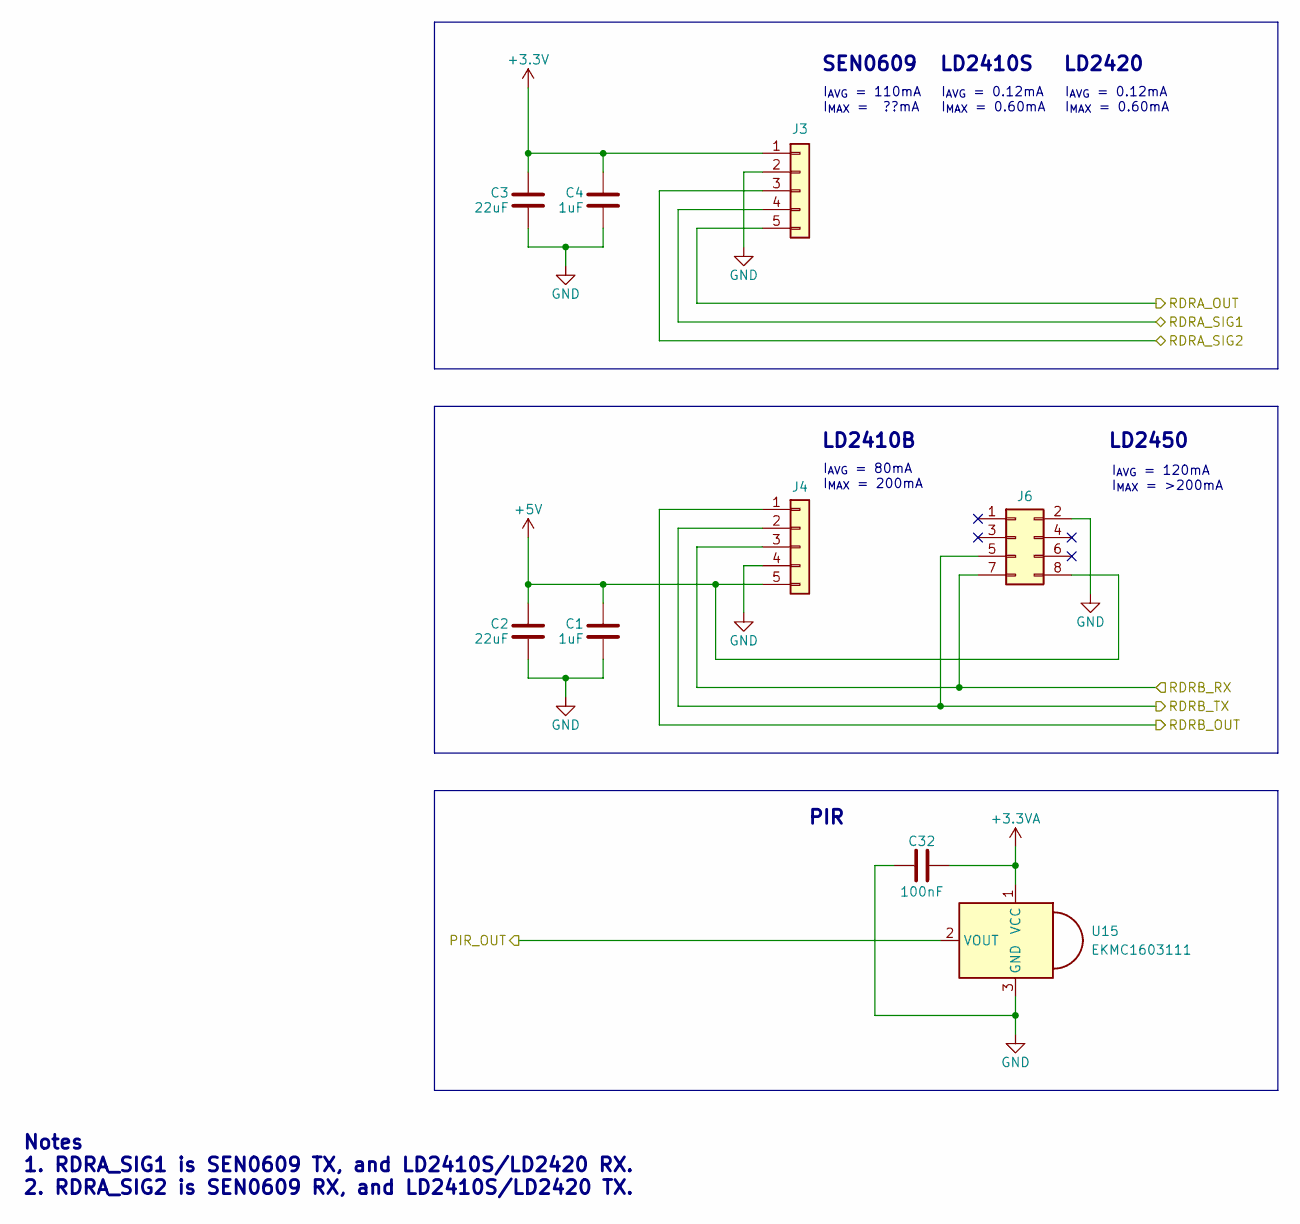
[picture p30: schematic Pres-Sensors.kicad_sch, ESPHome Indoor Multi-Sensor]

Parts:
C1, C4: 1uF; C_0402_1005Metric; Part Number CL05A105KA5NQNC
C2, C3: 22uF; C_0603_1608Metric; Part Number GRM188R60J226MEA0D
C32: 100nF; C_0402_1005Metric; Part Number CL05B104KB54PNC
J3: SEN0609; PinHeader_1x05_P2.54mm_Vertical; Part Number CES-105-01-T-S
J4: LD2410; PinSocket_1x05_P1.27mm_Vertical_SMD_Pin1Right; Part Number RSM-105-02-S-S
J6: LD2450; PinSocket_2x04_P2.00mm_Vertical_SMD; Part Number 79109-1003
U15: EKMC1603111; EKMC163111; Part Number EKMC1603111

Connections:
+3.3V: C3.1, C4.1, J3.1; also elsewhere on the board
+3.3VA: C32.2, U15.1 (VCC); also elsewhere on the board
+5V: C1.1, C2.1, J4.5, J6.8; also elsewhere on the board
/PIR_OUT: U15.2 (VOUT); also elsewhere on the board
/RDRA_OUT: J3.5; also elsewhere on the board
/RDRA_SIG1: J3.4; also elsewhere on the board
/RDRA_SIG2: J3.3; also elsewhere on the board
/RDRB_OUT: J4.1; also elsewhere on the board
/RDRB_RX: J4.3, J6.7; also elsewhere on the board
/RDRB_TX: J4.2, J6.5; also elsewhere on the board
GND: C1.2, C2.2, C3.2, C4.2, C32.1, J3.2, J4.4, J6.2, U15.3 (GND); also elsewhere on the board

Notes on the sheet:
I_{AVG} = 0.12mA I_{MAX} = 0.60mA
I_{AVG} = 110mA I_{MAX} = ??mA
LD2450
LD2410B
I_{AVG} = 80mA I_{MAX} = 200mA
PIR
LD2410S
LD2420
SEN0609
Notes 1. RDRA_SIG1 is SEN0609 TX, and LD2410S/LD2420 RX. 2. RDRA_SIG2 is SEN0609 RX, and LD2410S/LD2420 TX.
I_{AVG} = 120mA I_{MAX} = >200mA

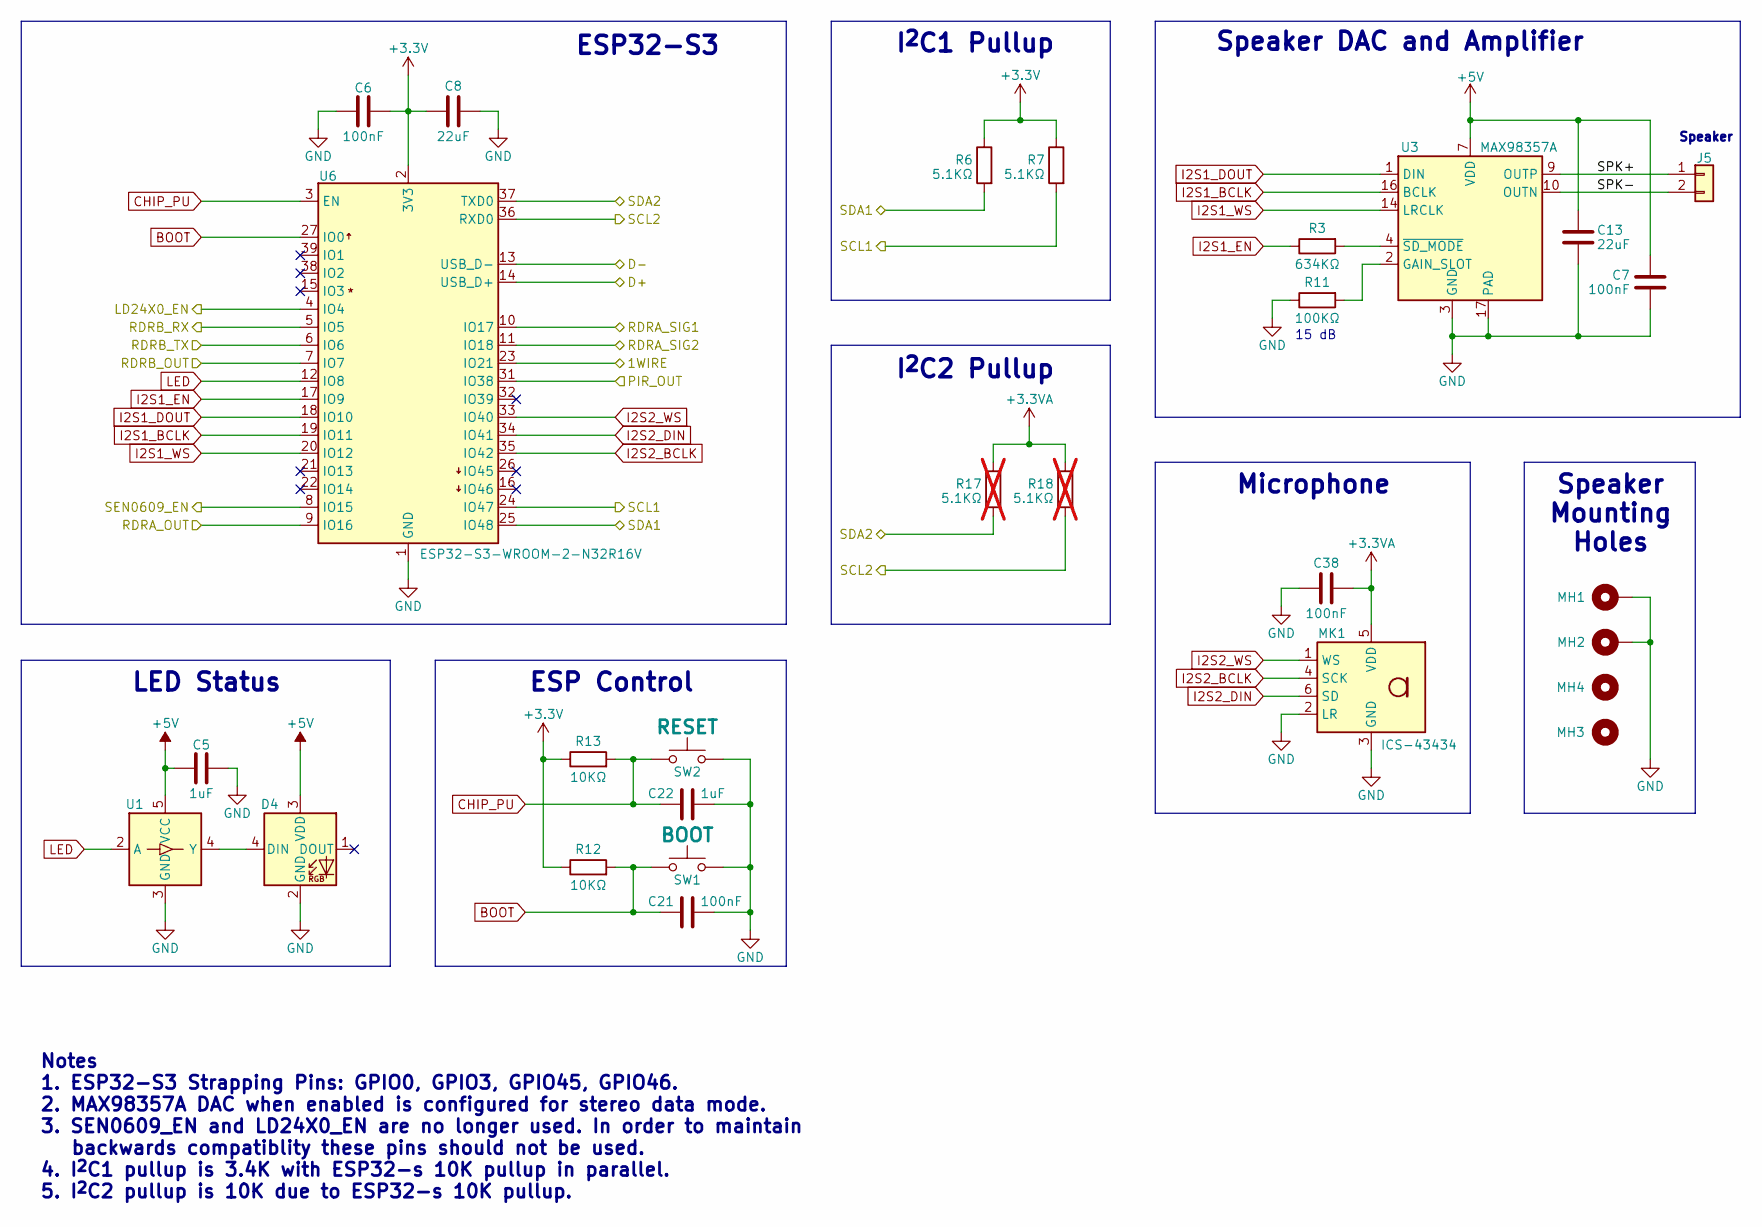
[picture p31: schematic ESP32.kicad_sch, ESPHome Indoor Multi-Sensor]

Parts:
C5, C22: 1uF; C_0402_1005Metric; Part Number CL05A105KA5NQNC
C6, C7, C21, C38: 100nF; C_0402_1005Metric; Part Number CL05B104KB54PNC
C8, C13: 22uF; C_0603_1608Metric; Part Number GRM188R60J226MEA0D
D4: NeoPixel_THT; LED_D5.0mm-4_RGB; Part Number 1938
J5: SPKR; PinHeader_1x02_P2.00mm_Vertical; Part Number CMS-251437-24SP-X8
MH1, MH2, MH3, MH4: MountingHole_2.2mm_M2_Pad
MK1: ICS-43434; InvenSense_ICS-43434-6_3.5x2.65mm; Part Number ICS-43434
R3: 634KΩ; R_0402_1005Metric; Part Number CRCW0402634KFKED
R6, R7: 5.1KΩ; R_0402_1005Metric; Part Number CRCW04025K10FKED
R11: 100KΩ; R_0402_1005Metric; Part Number CRCW0402100KFKED
R12, R13: 10KΩ; R_0402_1005Metric; Part Number CRCW040210K0FKED
R17, R18: 5.1KΩ; R_0402_1005Metric; Part Number CRCW04025K10FKED; not fitted
SW1: BOOT; SW_SPST_B3U-1000P-B; Part Number B3U-1000P
SW2: RESET; SW_SPST_B3U-1000P-B; Part Number B3U-1000P
U1: SN74LV1T34DBV; SOT-23-5; Part Number SN74LV1T34DBV
U3: MAX98357A; TQFN-16-1EP_3x3mm_P0.5mm_EP1.23x1.23mm; Part Number MAX98357AETE
U6: ESP32-S3-WROOM-2-N32R16V; ESP32-S3-WROOM-2; Part Number ESP32-S3-WROOM-2-N32R16V

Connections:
+3.3V: C6.2, C8.1, R6.1, R7.1, R12.1, R13.1, U6.2 (3V3); also elsewhere on the board
+3.3VA: C38.2, MK1.5 (VDD), R17.1, R18.1; also elsewhere on the board
+5V: C5.1, C7.1, C13.1, D4.3 (VDD), U1.5 (VCC), U3.7 (VDD), U3.8 (VDD); also elsewhere on the board
/1WIRE: U6.23 (IO21); also elsewhere on the board
/D+: U6.14 (USB_D+); also elsewhere on the board
/D-: U6.13 (USB_D-); also elsewhere on the board
/ESP32-S3/LD24X0_EN: U6.4 (IO4)
/ESP32-S3/SEN0609_EN: U6.8 (IO15)
/ESP32-S3/SPK+: J5.1, U3.9 (OUTP)
/ESP32-S3/SPK-: J5.2, U3.10 (OUTN)
/PIR_OUT: U6.31 (IO38); also elsewhere on the board
/RDRA_OUT: U6.9 (IO16); also elsewhere on the board
/RDRA_SIG1: U6.10 (IO17); also elsewhere on the board
/RDRA_SIG2: U6.11 (IO18); also elsewhere on the board
/RDRB_OUT: U6.7 (IO7); also elsewhere on the board
/RDRB_RX: U6.5 (IO5); also elsewhere on the board
/RDRB_TX: U6.6 (IO6); also elsewhere on the board
/SCL1: R7.2, U6.24 (IO47); also elsewhere on the board
/SCL2: R18.2, U6.36 (RXD0); also elsewhere on the board
/SDA1: R6.2, U6.25 (IO48); also elsewhere on the board
/SDA2: R17.2, U6.37 (TXD0); also elsewhere on the board
BOOT: C21.2, R12.2, SW1.2, U6.27 (IO0)
CHIP_PU: C22.1, R13.2, SW2.2, U6.3 (EN)
GND: C5.2, C6.1, C7.2, C8.2, C13.2, C21.1, C22.2, C38.1, D4.2 (GND), MH1.1, MH2.1, MK1.2 (LR), MK1.3 (GND), R11.1, SW1.1, SW2.1, U1.3 (GND), U3.3 (GND), U3.11 (GND), U3.15 (GND), U3.17 (PAD), U6.1 (GND), U6.40 (GND), U6.41 (GND); also elsewhere on the board
I2S1_BCLK: U3.16 (BCLK), U6.19 (IO11)
I2S1_DOUT: U3.1 (DIN), U6.18 (IO10)
I2S1_EN: R3.1, U6.17 (IO9)
I2S1_WS: U3.14 (LRCLK), U6.20 (IO12)
I2S2_BCLK: MK1.4 (SCK), U6.35 (IO42)
I2S2_DIN: MK1.6 (SD), U6.34 (IO41)
I2S2_WS: MK1.1 (WS), U6.33 (IO40)
LED: U1.2 (A), U6.12 (IO8)
unnamed: D4.4 (DIN), U1.4 (Y)
unnamed: R11.2, U3.2 (GAIN_SLOT)
unnamed: R3.2, U3.4 (~SD_MODE)

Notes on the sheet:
Speaker
I^{2}C2 Pullup
15 dB
ESP32-S3
Speaker Mounting Holes
I^{2}C1 Pullup
Notes 1. ESP32-S3 Strapping Pins: GPIO0, GPIO3, GPIO45, GPIO46. 2. MAX98357A DAC when enabled is configured for stereo data mode. 3. SEN0609_EN and LD24X0_EN are no longer used. In order to maintain backwards compatiblity these pins should not be used. 4. I^{2}C1 pullup is 3.4K with ESP32-s 10K pul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
Speaker DAC and Amplifier
ESP Control
Microphone
LED Status

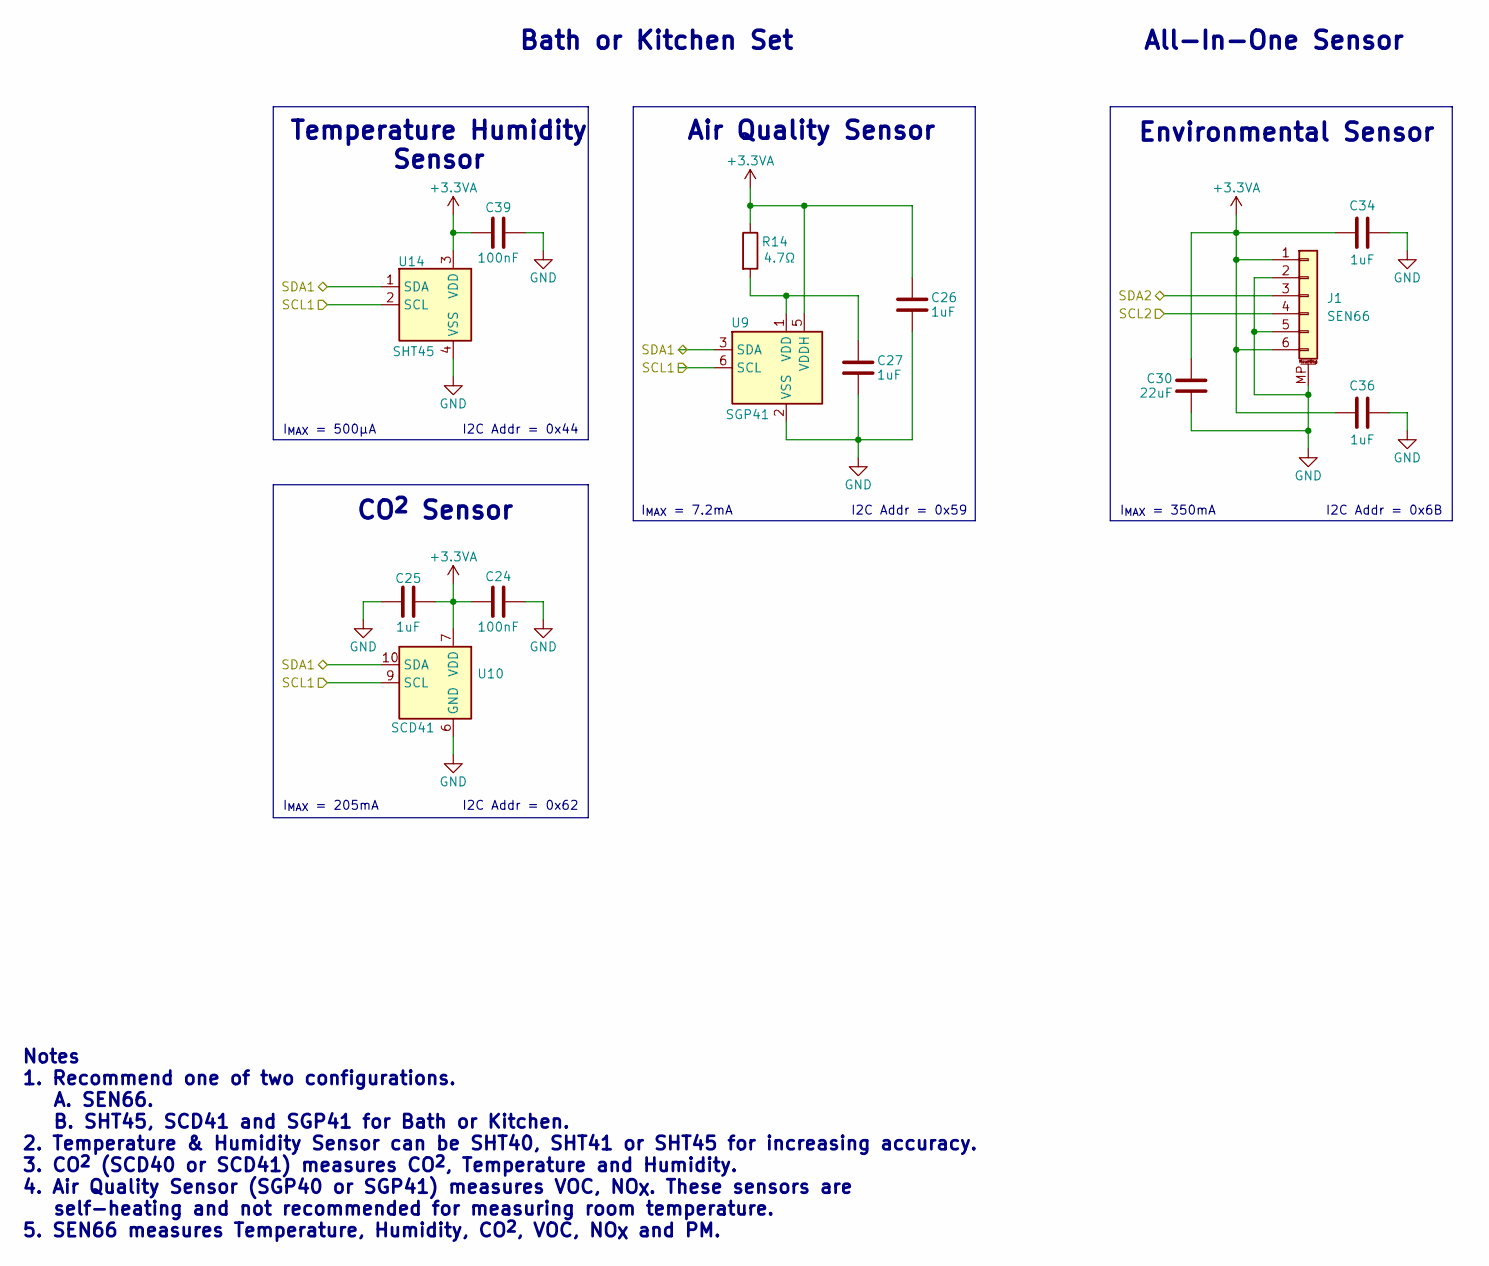
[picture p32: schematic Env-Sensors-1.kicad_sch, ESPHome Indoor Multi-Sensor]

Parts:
C24, C39: 100nF; C_0402_1005Metric; Part Number CL05B104KB54PNC
C25, C26, C27, C34, C36: 1uF; C_0402_1005Metric; Part Number CL05A105KA5NQNC
C30: 22uF; C_0603_1608Metric; Part Number GRM188R60J226MEA0D
J1: SEN66; JST_GH_BM06B-GHS-TBT_1x06-1MP_P1.25mm_Vertical; Part Number BM06B-GHS-TBT
R14: 4.7Ω; R_0402_1005Metric; Part Number CRCW04024R70FKED
U9: SGP41; XCDR_SGP40-D-R4; Part Number SGP41-D-R4
U10: SCD41; Sensirion_SCD4x-1EP_10.1x10.1mm_P1.25mm_EP4.8x4.8mm; Part Number SCD41-D-R2
U14: SHT45; Sensirion_DFN-4_1.5x1.5mm_P0.8mm_SHT4x_NoCentralPad; Part Number SHT45-AD1B-R2

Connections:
+3.3VA: C24.2, C25.2, C26.1, C30.1, C34.1, C36.1, C39.2, J1.1, J1.6, R14.1, U9.5 (VDDH), U10.7 (VDD), U10.19 (VDD), U14.3 (VDD); also elsewhere on the board
/SCL1: U9.6 (SCL), U10.9 (SCL), U14.2 (SCL); also elsewhere on the board
/SCL2: J1.4; also elsewhere on the board
/SDA1: U9.3 (SDA), U10.10 (SDA), U14.1 (SDA); also elsewhere on the board
/SDA2: J1.3; also elsewhere on the board
GND: C24.1, C25.1, C26.2, C27.2, C30.2, C34.2, C36.2, C39.1, J1.2, J1.5, J1.MP (MountPin), U9.2 (VSS), U9.4 (NA), U9.7 (EP), U10.6 (GND), U10.20 (GND), U10.21 (GND), U14.4 (VSS); also elsewhere on the board
unnamed: C27.1, R14.2, U9.1 (VDD)

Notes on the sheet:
I_{MAX} = 7.2mA
I2C Addr = 0x59
I2C Addr = 0x62
CO^{2} Sensor
Environmental Sensor
I_{MAX} = 350mA
Temperature Humidity Sensor
All-In-One Sensor
Bath or Kitchen Set
I2C Addr = 0x44
I2C Addr = 0x6B
I_{MAX} = 500µA
I_{MAX} = 205mA
Notes 1. Recommend one of two configurations. A. SEN66. B. SHT45, SCD41 and SGP41 for Bath or Kitchen. 2. Temperature & Humidity Sensor can be SHT40, SHT41 or SHT45 for increasing accuracy. 3. CO^{2} (SCD40 or SCD41) measures CO^{2}, Temperature and Humidity. 4. Air Quality Sensor (SGP40 or SGP41) 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
Air Quality Sensor

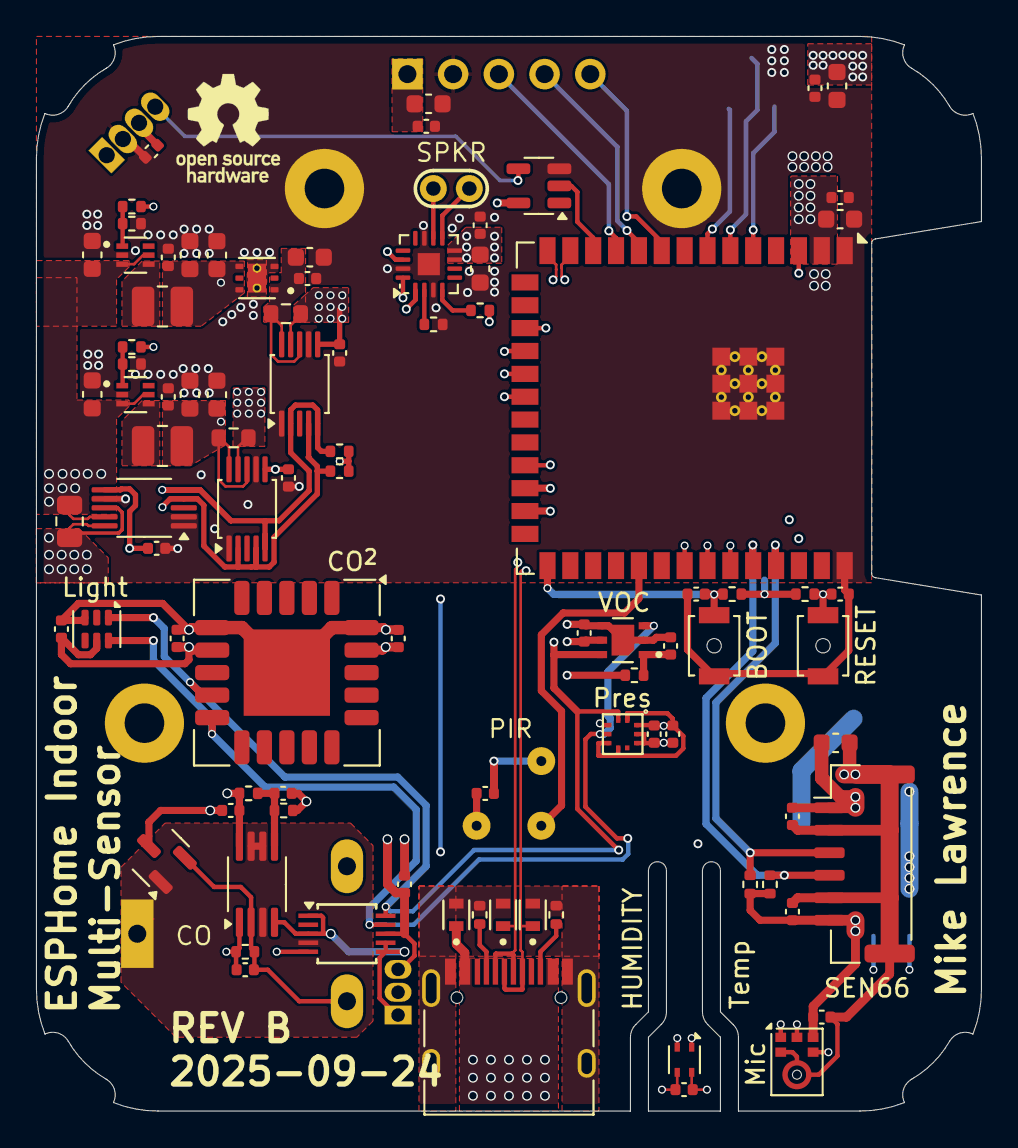
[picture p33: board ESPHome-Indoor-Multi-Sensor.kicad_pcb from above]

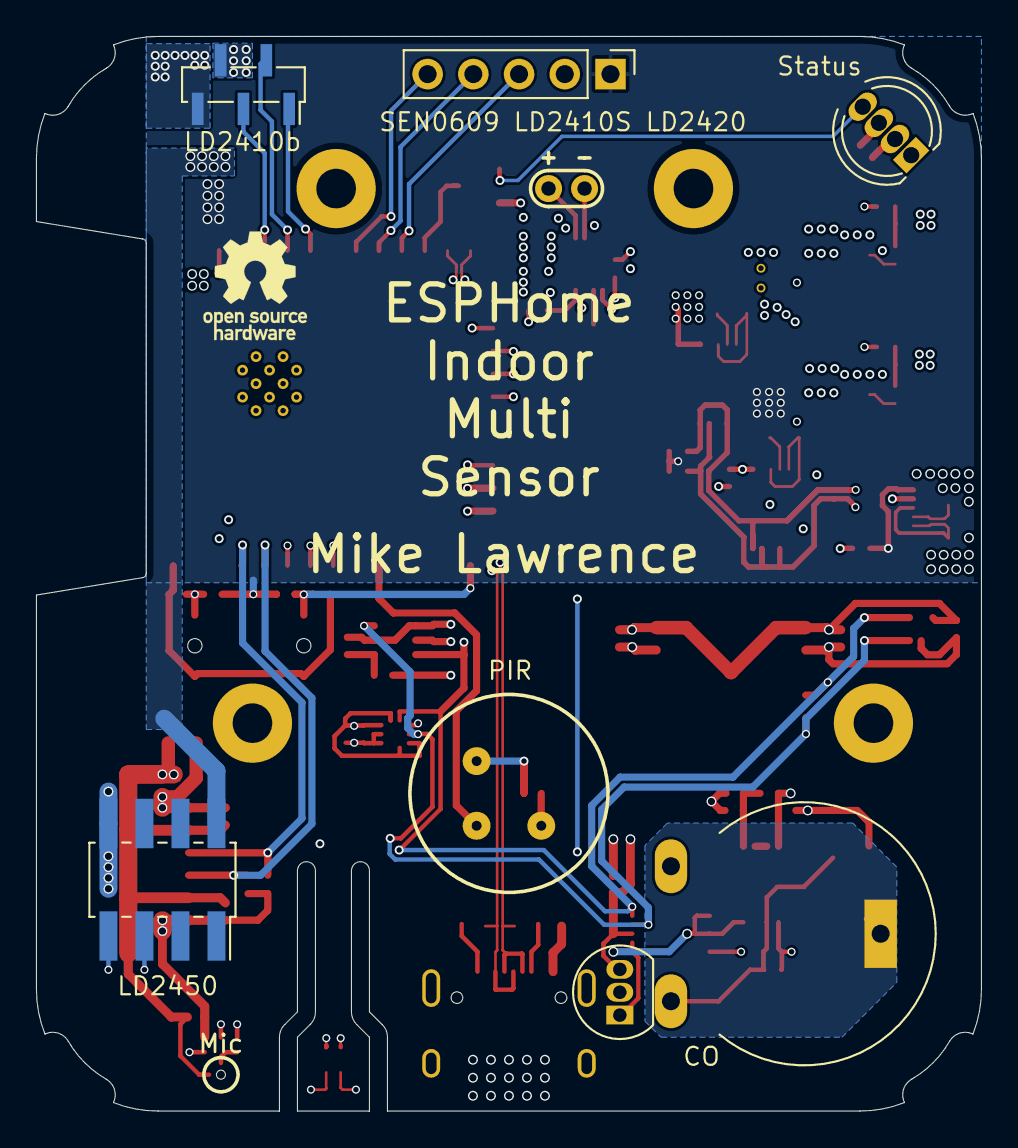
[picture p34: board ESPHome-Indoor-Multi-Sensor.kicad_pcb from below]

Board: 4 copper layers, 52.5 x 59.7 mm, 113 parts (9 on the bottom side), 48 nets.

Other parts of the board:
T1, T2, T3, T4, T5, T6, T7, T8, T9, T10: Tab
TEXT0, TEXT0#2: OSHW-Logo_5.7x6mm_SilkScreen

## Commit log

2025-09-23 Rev A Updates
    Support LD2410S and LD2420 Radars in same connector as C4001. Now using 3.3V instead of 5V.
    Removed Power control for Radars.
    Added DS18S20 to measure CO sensor temperature directly.
    Reworked SHT4X layout to reduce thermal transfer.
    [ESP32.kicad_sch, ESPHome-Indoor-Multi-Sensor-Enclosure.f3z, ESPHome-Indoor-Multi-Sensor.kicad_pcb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]
2025-09-23 Rev B Updates
    Fix image link error for enclosure
2025-09-23 Cleanup schematic, BOM and update gerber files
    [ESP32.kicad_sch, ESPHome-Indoor-Muiti-Sensor-BOM.csv, Env-Sensors-1.kicad_sch]
2025-09-23 Minor cleanup
    [ESPHome-Indoor-Multi-Sensor.kicad_pcb, Env-Sensors-1.kicad_sch]
2025-09-23 Add new ina228 to other power supplies
    Not finished
    [ESP32.kicad_sch, ESPHome-Indoor-Multi-Sensor.kicad_pcb, ESPHome-Indoor-Multi-Sensor.kicad_sch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]
2025-09-24 Rev B Updates finish adding power monitors for 3.3V and 3.3VA
    Removed speaker gain jumper
    [ESP32.kicad_sch, ESPHome-Indoor-Multi-Sensor.kicad_pcb, ESPHome-Indoor-Multi-Sensor.kicad_sch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]
2025-09-24 Add Rev B notes to schematic
    Update BOM
    [ESP32.kicad_sch, ESPHome-Indoor-Multi-Sensor.kicad_sch, Env-Sensors-1.kicad_sch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]
2025-09-29 BOM Updates
    No PCB changes. This is still Rev.B
    [ESP32.kicad_sch, ESPHome-Indoor-Muiti-Sensor-BOM.csv, ESPHome-Indoor-Multi-Sensor.kicad_sch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]
2025-10-01 Update Enclosure Files to latest
    Add Angle Wallplate
    [ESPHome Multi-Sensor-Enclosure v123.step, ESPHome-Indoor-Multi-Sensor-Angle-Wallplate-Bambu-Studio.3mf, ESPHome-Indoor-Multi-Sensor-Corner-Back-Body.step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]
2025-10-01 Rename Wallplate files
    [ESPHome-Indoor-Multi-Sensor-Angle-Wallplate-Cap-SEN66.step, ESPHome-Indoor-Multi-Sensor-Angle-Wallplate-Front-Body-No-PIR.step, ESPHome-Indoor-Multi-Sensor-Ang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]
2025-10-03 Add Stencil Jig step files and fusion project
    [Stencil Base.step, Stencil Frame.step, Stencil-Jig-80X80-ESPHome-Indoor-Muilti-Sensor-Rev-B-Fusion Project.f3d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]
2025-10-03 Update 3D Printing files
    [ESPHome Multi-Sensor-Enclosure v123.step, ESPHome-Indoor-Multi-Sensor-Angle-Wallplate-Bambu-Studio.3mf, ESPHome-Indoor-Multi-Sensor-Corner-Back-Body.step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]
2025-10-04 Adjustments to Jig
    Works better with PLA and 2mm stainless steel pins.
    Add hole under PCB to make it easier to remove the PCB.
    [Stencil Base.step, Stencil Frame.step, Stencil-Jig-80X80-ESPHome-Indoor-Muilti-Sensor-Rev-B-Fusion Project.f3d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]
2025-10-04 Fix missing USB-C cutout in front body
    [ESPHome-Indoor-Multi-Sensor-Angle-Wallplate-Bambu-Studio.3mf, ESPHome-Indoor-Multi-Sensor-Angle-Wallplate-Front-Body-No-PIR.step, ESPHome-Indoor-Multi-Sensor-A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]
2025-10-05 Design now uses one ina228 and two ina232 power sensors
    Reduces cost without sacrificing functionality. Mainly wanted power supply voltage and currents.
    [ESPHome-Indoor-Muiti-Sensor-BOM.csv, ESPHome-Indoor-Multi-Sensor.kicad_pcb, ESPHome-Indoor-Multi-Sensor.kicad_sch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]

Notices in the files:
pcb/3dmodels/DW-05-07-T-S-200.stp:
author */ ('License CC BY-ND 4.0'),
